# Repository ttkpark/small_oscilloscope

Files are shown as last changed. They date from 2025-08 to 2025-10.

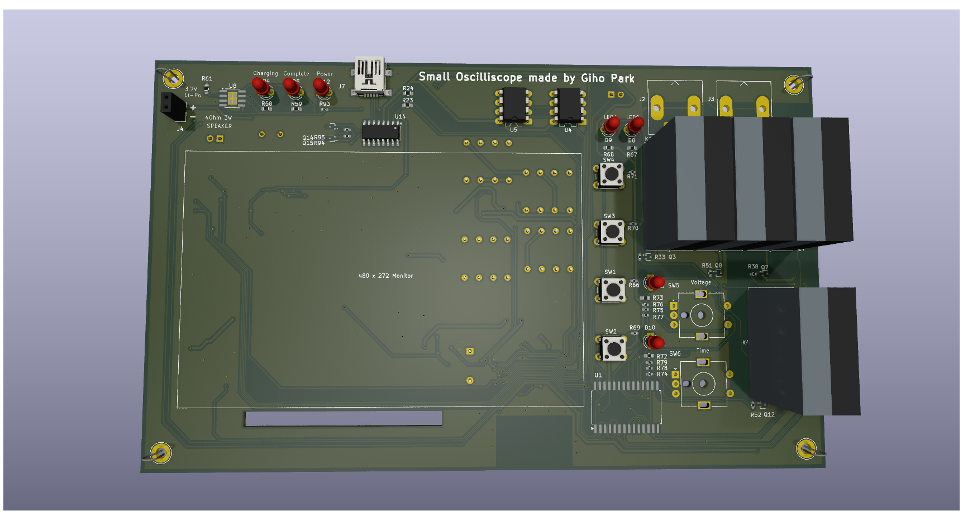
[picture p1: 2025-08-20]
hardware/small_oscilloscope/front.png

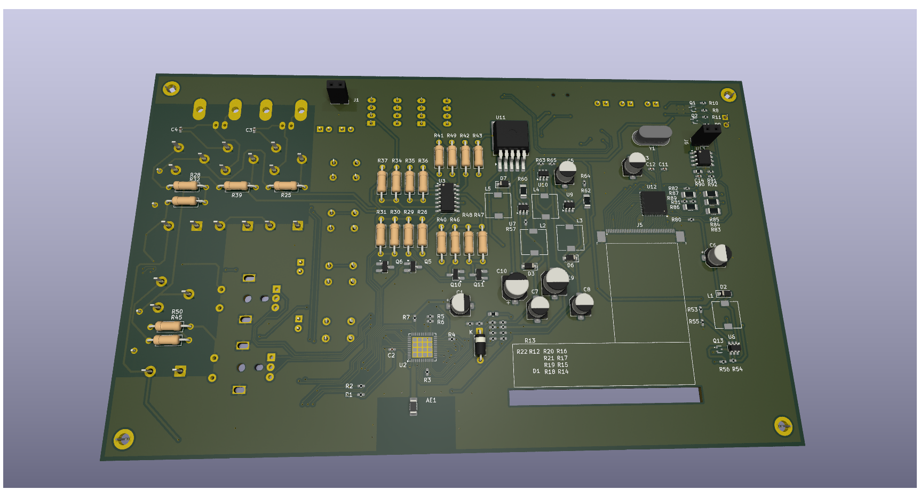
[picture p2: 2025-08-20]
hardware/small_oscilloscope/back.png

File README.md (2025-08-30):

# small_oscilloscope
480x272 small-but-full oscilloscope

## stpes to go

### 아날로그 회로
 - 오실로스코프 회로 방식 파악 필요
 - DSO138의 회로 구성을 확인

### 오실로스코프 UI
 - 제어점과 보여줄 점을 파악 필요
 - `사용자의 입력은 무엇이 되어야 하는가`
 - `오실로스코프의 아날로그 유닛에 대한 제어 범위는?`
 - `어느 점을 보여주어야 하는가`

 - 트리거 인식 : 샘플 내에서 level지점 통과 지점을 지점 정중앙으로 둔다.
 - 샘플링 후 트리거 인식이 아니라, 샘플링 하면서 트리거 인식하면 트리거 지점이 정중앙되도록 샘플 수집하고 마무리.
 - 즉 샘플링 -> 트리거 x, 트리거 -> 샘플링 o

## 전원
- 상시 전원 공급 Source : VBAT=2.7 ~ 4.2
- BAT 충전       : 5V -> VBAT=4.2 (TP4056)
- 배터리 승압 회로 : VBAT -> 5V    (EA2208)
- 양전압 생성 회로 : VBAT -> 12V   (EA2208)
- 음전압 생성 회로 : 12V -> -12V   (LM2576)
- 백라이트 회로    : VBAT -> 24V   (EA2208)
- 강하 회로       : 5V -> 3.3V    (5V->3.3V 전압 강하 보드)

## 구성요소
- 본체 중앙처리장치
   - 구성 부품 : ESP32-PICO-D4
   - 인터페이스 : GPIO, SPI, I2C, ADC, UART, DAC 제공

- GPIO 확장 칩 : CH423
   - 구성 부품 : CH423
   - 인터페이스 : 본체 인터페이스 I2C 사용
               입출력 GPIO IO0-7, 출력 GPIO OC0-15 제공

- 아날로그 어레이
   - 구성 부품 : 전압 강하 OP-AMP, 감쇠율 조절 FET 및 릴레이, AC/DC 선택 릴레이, TRIG 생성기
   - 인터페이스 : GPIO 확장 칩 OC0,OC2-6,OC8-11 사용
                본체 인터페이스 GPIO(GPIO9-10), ADC(GPIO34, GPIO4), DAC(GPIO25, GPIO26) 사용
- 그래픽
   - 구성 부품 : FT800Q-T, 480x272 Monitor
   - 인터페이스 : 본체 인터페이스 SPI, 본체 GPIO (GPIO27:INT) 사용

- 조작부
   - 구성 부품 : 버튼, ROTARY Encoder, LED
   - 인터페이스 : GPIO 확장 칩 IO0-5, OC12-15 사용

- 연결부
   - 구성 부품 : CH340, BOOT Mode selecting MOSFET
   - 인터페이스 : 본체 인터페이스 UART, 본체 GPIO 부팅 핀(GPIO0, EN) 사용

- 충전부
   - 구성 부품 : 배터리 및 TP4056
   - 인터페이스 : GPIO 확장 칩 IO6-7 사용

- 전원부
   - 구성 부품 : 레퍼런스 전압을 나누는 Voltage Divisor
   - 인터페이스 : 본체 ADC 레퍼런스 전압 포트(GPIO35-39)

# 핀맵
|position|name|usage|
|----|----|----|
|UART(TX=GPIO1,RX=GPIO3)|CH340|Interface; uploading & debugging port|
|I2C(CK=GPIO21,DA=GPIO22)|CH423s|Interface; controlls the MOSFETs|
|SPI(SCK=GPIO18,MISO=GPIO19,MOSI=GPIO23,SS=GPIO5)|FT800Q-T|Interface; graphical controller, speaker enabled, DE Mode|
|GPIO27|/INT|LCD FT800Q-T Interrupt Pin|

|GPIO12|RE1B|Digital Input; Rotary Encoder 1(Volt Div/Pos) B|
|GPIO13|RE1A|Digital Input; Rotary Encoder 1(Volt Div/Pos) A|
|GPIO14|RE0B|Digital Input; Rotray Encoder 0(Time Div/Pos) B|
|GPIO15|RE0A|Digital Input; Rotray Encoder 0(Time Div/Pos) A|

|GPIO9|TRIG0|Digital Input, interrupt; open-drain, LOW if TRIG<ADC0|
|GPIO10|TRIG1|Digital Input, interrupt; open-drain, LOW if TRIG<ADC1|
|GPIO25|TRIG|Analog Output;  Trigger Output(same level with ADC0,1 pin)|
|GPIO34|ADC0|Analog Input;  Channel 0 input|
|GPIO4|ADC1|Analog Input;  Channel 1 input|
|GPIO26|TESTPIN|1kHz Signal Output pin|

|GPIO35|VREF3V3|Analog Reference Input;  3V3(VDD) ref, Vin=V33/2|
|GPIO36|VREFBAT|Analog Reference Input;  VBAT ref, Vin=VBAT/2|
|GPIO37|VREF5V |Analog Reference Input;  5V ref, Vin=V5/4.333|
|GPIO38|VREF12V|Analog Reference Input;  12V ref,Vin=V12/6.732|
|GPIO39|VREF135|Analog Reference Input;  2.7V ref, Vin=1.35V |

|CH423s-IO0|RE0P|Input; Rotary Encoder 0 Pushbutton(LOW Active)|
|CH423s-IO1|RE1P|Input; Rotary Encoder 1 Pushbutton(LOW Active)|
|CH423s-IO2|SW0|Input; button 0(LOW ACTIVE)|
|CH423s-IO3|SW1|Input; button 1(LOW ACTIVE)|
|CH423s-IO4|SW2|Input; button 2(LOW ACTIVE)|
|CH423s-IO5|SW3|Input; button 3(LOW ACTIVE)|
|CH423s-IO6|STDBY|Input; BATTERY 충전 완료면 HIGH|
|CH423s-IO7|CHRG|Input; BATTERY 충전 중이면 HIGH|
|CH423s-OC0|Q1|Output; Line 0 DC input analog switch|
|CH423s-OC1|BACKLIGHT|Output; LCD BACKLIGHT|
|CH423s-OC2|Q3|Output; Line 0 1차 1/10 감쇠|
|CH423s-OC3|Q4|Output; Line 0 1차 1/100 감쇠|
|CH423s-OC4|Q5|Output; Line 0 2차 1/2 감쇠|
|CH423s-OC5|Q6|Output; Line 0 2차 1/5 감쇠|
|CH423s-OC6|Q7|Output; Line 1 DC input analog switch|
|CH423s-OC7|-|Output; -|
|CH423s-OC8|Q9|Output; Line 1 1차 1/10 감쇠|
|CH423s-OC9|Q10|Output; Line 1 1차 1/100 감쇠|
|CH423s-OC10|Q11|Output; Line 1 2차 1/2 감쇠|
|CH423s-OC11|Q12|Output; Line 1 2차 1/5 감쇠|
|CH423s-OC12|LED0|Output; GP LED (Red)|
|CH423s-OC13|LED1|Output; GP LED (Green)|
|CH423s-OC14|LEDRE0|Output; Rotary Encoder 0 LED (Green)|
|CH423s-OC15|LEDRE1|Output; Rotary Encoder 1 LED (Green)|

# 하드웨어 연결 및 기능 구조

## 본체 중앙처리장치
   - 구성 부품 : ESP32-PICO-D4
   - 인터페이스 : GPIO, SPI, I2C, ADC, UART, DAC 제공

## GPIO 확장 칩 : CH423
   - 구성 부품 : CH423
   - 인터페이스 : 본체 인터페이스 I2C 사용
               입출력 GPIO IO0-7, 출력 GPIO OC0-15 제공
### 인터페이스 상세
|position|name|usage|
|----|----|----|
|I2C(CK=GPIO21,DA=GPIO22)|CH423s|Interface; controlls the MOSFETs|

### 설정
- 주소는 0x20이다. (7-bit addr)
analog_test_simple.c:84 esp_err_t test_ch423_circuit_simple(uint8_t *read_data) 의 테스트 함수에서 초기화 및 읽고 쓰는 법에 대해 쓰여 있다.

## 아날로그 어레이
- 구성 부품 : 전압 강하 OP-AMP, 감쇠율 조절 FET 및 릴레이, AC/DC 선택 릴레이, TRIG 생성기
- 인터페이스 : GPIO 확장 칩 OC0,OC2-6,OC8-11 사용
             본체 인터페이스 GPIO(GPIO9-10), ADC(GPIO34, GPIO4), DAC(GPIO25, GPIO26) 사용
### 인터페이스 상세
|position|name|usage|
|----|----|----|
|GPIO9|TRIG0|Digital Input, interrupt; open-drain, LOW if TRIG<ADC0|
|GPIO10|TRIG1|Digital Input, interrupt; open-drain, LOW if TRIG<ADC1|
|GPIO25|TRIG|Analog Output;  Trigger Output(same level with ADC0,1 pin)|
|GPIO34|ADC0|Analog Input;  Channel 0 input|
|GPIO35|ADC1|Analog Input;  Channel 1 input|
|GPIO26|TESTPIN|1kHz Signal Output pin|

|CH423s-OC0|Q1|Output; Line 0 DC input analog switch|
|CH423s-OC2|Q3|Output; Line 0 1차 1/10 감쇠|
|CH423s-OC3|Q4|Output; Line 0 1차 1/100 감쇠|
|CH423s-OC4|Q5|Output; Line 0 2차 1/2 감쇠|
|CH423s-OC5|Q6|Output; Line 0 2차 1/5 감쇠|
|CH423s-OC6|Q7|Output; Line 1 DC input analog switch|
|CH423s-OC8|Q9|Output; Line 1 1차 1/10 감쇠|
|CH423s-OC9|Q10|Output; Line 1 1차 1/100 감쇠|
|CH423s-OC10|Q11|Output; Line 1 2차 1/2 감쇠|
|CH423s-OC11|Q12|Output; Line 1 2차 1/5 감쇠|

### 프로브부터 ADC 포트까지 감쇠 회로 및 전압의 관계
- [출력] - [AC/DC 선택]  -   [1차 감쇠 회로] - [2차 감쇠 회로] - 레벨 쉬프터

### 감쇠율 조정 로직 : AC/DC 선택
|Q1/Q7|상태|
|--|--|
|0|DC입력(원본)|
|1|AC입력(AC성분만)|

### 감쇠율 조정 로직 : 1차 감쇠기
|Q3/Q9|Q4/Q10|상태|
|--|--|alpha_1|
|0|0|1|
|0|1|1/100|
|1|0|1/10|
|1|1|INVALD|
- V1 = alpha_1 * Vi

### 감쇠율 조정 로직 : 2차 감쇠기
|Q5/Q11|Q6/Q12|상태|
|--|--|alpha_2|
|0|0|1|
|0|1|1/5|
|1|0|1/2|
|1|1|INVALD|
- V2 = alpha_2 * V1

### 레벨 쉬프터 식
- Vadc = 8 * V2 + (V12/7.2)

### 출력과 ADC 입력의 관계
- Vadc = 8 * alpha_2 * alpha_1 * Vi + (V12 / 7.2)
- alpha_2,alpha_1은 1차 2차 감쇠값, Vadc는 adc포트 전압, Vi는 프로브 전압, V12는 12V레인 전압

### 트리거
- TRIG0, TRIG1 핀은 pull-up되어야 한다.
|TRIG>ADCn|TRIGn|
|--|--|
|true|HIGH|
|false|LOW|

## 그래픽
   - 구성 부품 : FT800Q-T, 480x272 Monitor
   - 인터페이스 : 본체 인터페이스 SPI, 본체 GPIO (GPIO27:INT) 사용

|position|name|usage|
|----|----|----|
|SPI(SCK=GPIO18,MISO=GPIO19,MOSI=GPIO23,SS=GPIO5)|FT800Q-T|Interface; graphical controller, speaker enabled, DE Mode|
|GPIO27|/INT|LCD FT800Q-T Interrupt Pin|
|CH423s-OC1|BACKLIGHT|Output; LCD BACKLIGHT|
### 사용법
- 사전에 반드시 **CH423이 먼저 초기화되고, BACKLIGHT 핀을 LOW 해야 한다.**
- 아래 코드처럼 초기화하고, 그림을 그리고 효과음을 낸다.
```c
   // FT800 초기화
    if (!initFT800()) {
        ESP_LOGI(TAG, "FT800 test passed");
    } else {
        ESP_LOGE(TAG, "FT800 test failed");
    }
    vTaskDelay(pdMS_TO_TICKS(1000));

    spi_speedup();
    
    // FT800 사용
	 clrscr();
    while(1){
		static uint32_t frames = 0;
        uint32_t frames_old = frames;
        frames = HOST_MEM_RD32(REG_FRAMES);
        if(frames_old != frames)
        {
            lcd_start_screen(frames);
            //ESP_LOGI(TAG, "FRAMES: %ld", frames);

            char str[100];
            sprintf(str, "FRAMES: %ld", frames);
            cmd(COLOR_RGB(0xDE,0xDE,0xDE));
            cmd_text(10,230, 27,0, str);
            
            memset(str, 0, sizeof(str));
            sprintf(str, "GPIO12 = %d", gpio_get_level(12));
            cmd(COLOR_RGB(0xDE,0xDE,0xDE));
            cmd_text(470,230, 26,OPT_RIGHTX, str);

            cmd(DISPLAY());
            cmd(CMD_SWAP);	
        }
        vTaskDelay(pdMS_TO_TICKS(1));
    }

    // 소리 내기
   HOST_MEM_WR8(REG_VOL_SOUND, 0xFF);      	
   switch((frames%180)/60){
      case 0:
         HOST_MEM_WR16(REG_SOUND, 0x50);     
         break;
      case 1:
         HOST_MEM_WR16(REG_SOUND, 0x51);
         break;
      case 2:
         HOST_MEM_WR16(REG_SOUND, 0x56);
         break;
   }
   HOST_MEM_WR8(REG_PLAY, 1); 
   
```

## 조작부
   - 구성 부품 : 버튼, ROTARY Encoder, LED
   - 인터페이스 : GPIO 확장 칩 IO0-5, OC12-15 사용

|position|name|usage|
|----|----|----|
|GPIO12|RE1B|Digital Input; Rotary Encoder 1(Volt Div/Pos) B|
|GPIO13|RE1A|Digital Input; Rotary Encoder 1(Volt Div/Pos) A|
|GPIO14|RE0B|Digital Input; Rotray Encoder 0(Time Div/Pos) B|
|GPIO15|RE0A|Digital Input; Rotray Encoder 0(Time Div/Pos) A|
|CH423s-IO0|RE0P|Input; Rotary Encoder 0 Pushbutton(LOW Active)|
|CH423s-IO1|RE1P|Input; Rotary Encoder 1 Pushbutton(LOW Active)|
|CH423s-IO2|SW0|Input; button 0(LOW ACTIVE)|
|CH423s-IO3|SW1|Input; button 1(LOW ACTIVE)|
|CH423s-IO4|SW2|Input; button 2(LOW ACTIVE)|
|CH423s-IO5|SW3|Input; button 3(LOW ACTIVE)|
|CH423s-OC12|LED0|Output; GP LED (Red)|
|CH423s-OC13|LED1|Output; GP LED (Green)|
|CH423s-OC14|LEDRE0|Output; Rotary Encoder 0 LED (Green)|
|CH423s-OC15|LEDRE1|Output; Rotary Encoder 1 LED (Green)|

- 로터리 스위치의 움직임 방향, 버튼의 눌림을 알 수 있고, LED 4개로 확인할 수 있다.

## 연결부
   - 구성 부품 : CH340, BOOT Mode selecting MOSFET
   - 인터페이스 : 본체 인터페이스 UART, 본체 GPIO 부팅 핀(GPIO0, EN) 사용

|position|name|usage|
|----|----|----|
|UART(TX=GPIO1,RX=GPIO3)|CH340|Interface; uploading & debugging port|

## 충전부
   - 구성 부품 : 배터리 및 TP4056
   - 인터페이스 : GPIO 확장 칩 IO6-7 사용
|position|name|usage|
|----|----|----|
|CH423s-IO6|STDBY|Input; BATTERY 충전 완료면 HIGH|
|CH423s-IO7|CHRG|Input; BATTERY 충전 중이면 HIGH|

### 충전 상태 설명
|STDBY|CHRG|상태|
|--|--|--|
|LOW |LOW |외부전원 분리됨|
|LOW |HIGH|충전 중|
|HIGH|LOW |충전 완료|
|HIGH|HIGH|INVALID, 아마도 충전중|

## 전원부
   - 구성 부품 : 레퍼런스 전압을 나누는 Voltage Divisor
   - 인터페이스 : 본체 ADC 레퍼런스 전압 포트(GPIO35-39)

### 인터페이스 상세
|position|name|usage|
|----|----|----|
|GPIO36|VREFBAT|Analog Reference Input;  VBAT ref, Vin=VBAT/2|
|GPIO37|VREF5V |Analog Reference Input;  5V ref, Vin=V5/4.333|
|GPIO38|VREF12V|Analog Reference Input;  12V ref,Vin=V12/6.732|
|GPIO39|VREF135|Analog Reference Input;  2.7V ref, Vin=1.35V |

### 사용법
- VREF135 포트는 제너 다이오드로 연결된 거의 신뢰성 있는 전압이다. 이것을 기준으로 ADC Max Volt를 역산한다.(=VDD)
- VREFBAT의 입력을 전압으로 변환해 배터리 전압을 추출한다.
- VREF5V, 12V의 ADC입력을 전압으로 변환해 각 레인의 전압을 추출한다.
- VREF3V3은 VDD로 계산되지만, 검증용으로 예비로 전압을 추출한다.

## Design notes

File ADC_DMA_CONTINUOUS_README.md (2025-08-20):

# ESP-IDF ADC DMA Continuous Mode 구현

이 프로젝트는 ESP-IDF v5.4를 사용하여 ADC를 DMA로 끊임없이 읽는 방법을 구현한 것입니다.

## 개요

ESP32의 ADC를 Continuous Mode로 설정하여 DMA를 통해 끊임없이 데이터를 수집할 수 있습니다. 이 방식은 다음과 같은 장점이 있습니다:

- **높은 샘플링 속도**: 최대 10kHz까지 가능
- **CPU 부하 감소**: DMA가 자동으로 데이터를 처리
- **실시간 처리**: 인터럽트 기반으로 즉시 데이터 처리
- **버퍼링**: 1024 샘플 버퍼로 데이터 손실 방지

## 주요 기능

### 1. ADC Continuous Mode 초기화
```c
esp_err_t adc_dma_continuous_init(void);
```

### 2. ADC Continuous Mode 시작/정지
```c
esp_err_t adc_dma_continuous_start(void);
esp_err_t adc_dma_continuous_stop(void);
```

### 3. 데이터 접근 함수들
```c
// 전체 버퍼 데이터 가져오기
esp_err_t adc_dma_get_data(uint32_t *channel_0_data, uint32_t *channel_1_data, uint32_t *data_count);

// 최신 전압값 가져오기 (캘리브레이션 적용)
esp_err_t adc_dma_get_latest_voltage(uint32_t *voltage_ch0_mv, uint32_t *voltage_ch1_mv);

// 통계 정보 가져오기
esp_err_t adc_dma_get_statistics(uint32_t *min_ch0, uint32_t *max_ch0, uint32_t *avg_ch0,
                                uint32_t *min_ch1, uint32_t *max_ch1, uint32_t *avg_ch1);
```

## 설정

### ADC 채널
- **ADC1_CH0 (GPIO36)**: 첫 번째 채널
- **ADC1_CH1 (GPIO37)**: 두 번째 채널

### 샘플링 설정
- **샘플링 주파수**: 10kHz
- **버퍼 크기**: 1024 샘플
- **해상도**: 12비트
- **감쇠**: 11dB (0-3.3V 범위)

## 사용 방법

### 1. 기본 사용법

```c
#include "adc_dma_continuous.h"

void app_main(void) {
    // ADC DMA Continuous Mode 초기화
    esp_err_t ret = adc_dma_continuous_init();
    if (ret != ESP_OK) {
        ESP_LOGE(TAG, "ADC DMA init failed");
        return;
    }
    
    // ADC DMA Continuous Mode 시작
    ret = adc_dma_continuous_start();
    if (ret != ESP_OK) {
        ESP_LOGE(TAG, "ADC DMA start failed");
        return;
    }
    
    // 데이터 읽기
    uint32_t voltage_ch0_mv, voltage_ch1_mv;
    while (1) {
        ret = adc_dma_get_latest_voltage(&voltage_ch0_mv, &voltage_ch1_mv);
        if (ret == ESP_OK) {
            printf("CH0: %lumV, CH1: %lumV\n", voltage_ch0_mv, voltage_ch1_mv);
        }
        vTaskDelay(pdMS_TO_TICKS(100));
    }
}
```

### 2. 테스트 실행

프로젝트에 포함된 테스트를 실행하려면:

```c
// app_main.c에서 주석을 해제
start_adc_dma_test();        // 상세한 테스트
start_adc_monitor();         // 실시간 모니터링
```

### 3. 전체 버퍼 데이터 처리

```c
uint32_t channel_0_data[1024];
uint32_t channel_1_data[1024];
uint32_t data_count;

esp_err_t ret = adc_dma_get_data(channel_0_data, channel_1_data, &data_count);
if (ret == ESP_OK) {
    // 1024개의 샘플 데이터 처리
    for (int i = 0; i < data_count; i++) {
        // 데이터 처리 로직
    }
}
```

## 파일 구조

```
main/
├── adc_dma_continuous.c    # ADC DMA Continuous Mode 구현
├── adc_dma_continuous.h    # 헤더 파일
├── adc_dma_test.c         # 테스트 및 예제 코드
├── adc_dma_test.h         # 테스트 헤더 파일
└── app_main.c             # 메인 애플리케이션
```

## 빌드 및 실행

1. **프로젝트 빌드**:
   ```bash
   idf.py build
   ```

2. **플래시 및 모니터**:
   ```bash
   idf.py flash monitor
   ```

3. **ADC DMA 테스트 실행**:
   - `app_main.c`에서 `start_adc_dma_test()` 주석 해제
   - 또는 `start_adc_monitor()` 주석 해제

## 주의사항

1. **ADC 채널 제한**: ESP32에서는 ADC1과 ADC2를 동시에 사용할 때 제한이 있습니다.
2. **WiFi 사용**: ADC2를 사용할 때는 WiFi와 충돌할 수 있습니다.
3. **메모리 사용**: DMA 버퍼는 상당한 메모리를 사용합니다.
4. **캘리브레이션**: 정확한 측정을 위해서는 ADC 캘리브레이션이 필요합니다.

## 성능 특성

- **샘플링 속도**: 10kHz (설정 가능)
- **지연 시간**: < 1ms
- **CPU 사용률**: < 5% (DMA 사용으로 인해)
- **메모리 사용**: ~8KB (1024 샘플 × 2 채널 × 4바이트)

## 문제 해결

### 1. 초기화 실패
- ADC 채널이 올바르게 설정되었는지 확인
- 메모리 부족 여부 확인

### 2. 데이터 손실
- 큐 크기 증가
- 처리 속도 향상

### 3. 정확도 문제
- ADC 캘리브레이션 확인
- 노이즈 필터링 적용

## 확장 가능성

이 구현은 다음과 같이 확장할 수 있습니다:

1. **더 많은 채널**: ADC 패턴 설정 수정
2. **더 높은 샘플링 속도**: 설정 조정
3. **트리거 기능**: 특정 조건에서만 데이터 수집
4. **데이터 저장**: SD카드나 플래시에 저장
5. **실시간 분석**: FFT, 필터링 등

## 참고 자료

- [ESP-IDF ADC Continuous Mode 문서](https://docs.espressif.com/projects/esp-idf/en/latest/esp32/api-reference/peripherals/adc_continuous.html)
- [ESP32 ADC 가이드](https://docs.espressif.com/projects/esp-idf/en/latest/esp32/api-reference/peripherals/adc.html)

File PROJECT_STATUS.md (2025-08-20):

# Small Oscilloscope Project Status

## 프로젝트 개요
Small Oscilloscope는 ESP32 기반의 소형 오실로스코프 프로젝트입니다.

## 현재 상태 (2024-01-XX)

### ✅ 완료된 기능

#### 1. 하드웨어 설계
- [x] KiCad PCB 설계 완료
- [x] FT800 LCD 인터페이스 회로
- [x] CH423 I2C IO 확장 회로
- [x] 아날로그 입력 회로 (ADC)
- [x] 로터리 인코더 인터페이스
- [x] 트리거 회로
- [x] 전원 공급 회로

#### 2. 기본 소프트웨어
- [x] ESP-IDF 프로젝트 설정
- [x] FT800 LCD 드라이버 구현
- [x] 기본 GPIO 테스트
- [x] ADC 읽기 테스트
- [x] I2C CH423 테스트
- [x] 로터리 인코더 테스트

#### 3. 아날로그 테스트 시스템 ✅ **NEW**
- [x] CH423 테스트 회로 구현
- [x] 채널별 AC/DC 모드 선택 기능
- [x] 채널별 1차/2차 감쇠율 설정 (1X, 10X, 100X, 1000X)
- [x] 실시간 시리얼 출력 기능
- [x] 웹 서버를 통한 파형 표시
- [x] Python 테스트 스크립트
- [x] 종합 테스트 시스템

### 🔄 진행 중인 작업

#### 1. LCD 모니터 문제 해결
- [ ] FT800 LCD 동작 문제 디버깅
- [ ] SPI 통신 최적화
- [ ] 백라이트 제어 개선

#### 2. 아날로그 회로 테스트
- [ ] 실제 하드웨어에서 아날로그 테스트 실행
- [ ] ADC 캘리브레이션 개선
- [ ] 노이즈 필터링 적용

### 📋 예정된 작업

#### 1. 오실로스코프 핵심 기능
- [ ] 트리거 시스템 구현
- [ ] 시간축 제어 (Time/Div)
- [ ] 전압축 제어 (Volt/Div)
- [ ] 파형 저장 및 재생
- [ ] 측정 기능 (주파수, 진폭, 주기 등)

#### 2. 사용자 인터페이스
- [ ] LCD 터치 인터페이스 구현
- [ ] 메뉴 시스템
- [ ] 설정 저장/불러오기
- [ ] 다국어 지원

#### 3. 고급 기능
- [ ] FFT 스펙트럼 분석
- [ ] 자동 측정 기능
- [ ] 데이터 로깅
- [ ] 원격 제어 인터페이스

## 기술 스택

### 하드웨어
- **MCU**: ESP32-WROOM-32
- **LCD**: FT800 (SPI 인터페이스)
- **IO 확장**: CH423 (I2C)
- **ADC**: ESP32 내장 ADC (12-bit)
- **인코더**: ALPS EC11E

### 소프트웨어
- **프레임워크**: ESP-IDF v5.4
- **언어**: C/C++
- **통신**: SPI, I2C, UART
- **웹 서버**: ESP HTTP Server
- **테스트 도구**: Python + matplotlib

## 파일 구조

```
small_oscilloscope/
├── main/
│   ├── app_main.c              # 메인 애플리케이션
│   ├── ft800.c                 # FT800 LCD 드라이버
│   ├── ft800.h                 # FT800 헤더
│   ├── oscilloscope_test.c     # 기본 테스트 함수
│   ├── oscilloscope_test.h     # 기본 테스트 헤더
│   ├── analog_test.c           # 아날로그 테스트 시스템 ✅
│   ├── analog_test.h           # 아날로그 테스트 헤더 ✅
│   └── CMakeLists.txt          # 빌드 설정
├── hardware/
│   └── small_oscilloscope/     # KiCad 프로젝트
├── test_analog.py              # Python 테스트 스크립트 ✅
├── ANALOG_TEST_README.md       # 아날로그 테스트 문서 ✅
├── PROJECT_STATUS.md           # 이 파일
└── README.md                   # 프로젝트 개요
```

## 최근 업데이트 (2024-01-XX)

### 아날로그 테스트 시스템 구현 완료 ✅

요청하신 모든 아날로그 테스트 기능을 구현했습니다:

1. **CH423 테스트 회로**
   - I2C를 통한 CH423 IO 확장 칩 테스트
   - 테스트 패턴 출력 및 읽기 기능
   - 자동 감지 및 오류 처리

2. **채널별 AC/DC 모드 선택**
   - 각 채널 독립적으로 DC/AC 모드 설정
   - 실시간 모드 변경 지원
   - 설정 상태 시리얼 출력

3. **감쇠율 설정**
   - 1차/2차 감쇠율 독립 설정 (1X, 10X, 100X, 1000X)
   - 채널별 개별 설정 지원
   - 설정값 실시간 모니터링

4. **시리얼 출력**
   - 10Hz 실시간 데이터 출력
   - ADC 값, 채널 설정, CH423 상태 포함
   - 구조화된 데이터 형식

5. **웹 인터페이스**
   - 실시간 파형 표시 (Canvas 기반)
   - 채널 설정 웹 인터페이스
   - 실시간 데이터 모니터링
   - 반응형 디자인

6. **Python 테스트 도구**
   - 시리얼 데이터 수집 및 파싱
   - matplotlib을 통한 파형 플롯
   - 명령행 인터페이스
   - 자동화된 테스트 기능

### 주요 특징

- **실시간 성능**: 10Hz 업데이트율로 실시간 모니터링
- **멀티태스킹**: FreeRTOS 기반 병렬 처리
- **웹 기반**: 브라우저를 통한 원격 제어
- **확장 가능**: 모듈화된 설계로 기능 확장 용이
- **문서화**: 상세한 API 문서 및 사용법 제공

## 다음 단계

1. **하드웨어 테스트**: 실제 보드에서 아날로그 테스트 실행
2. **LCD 문제 해결**: FT800 동작 문제 디버깅
3. **성능 최적화**: ADC 샘플링율 및 정확도 개선
4. **오실로스코프 기능**: 트리거, 시간축, 측정 기능 구현

## 빌드 및 테스트

```bash
# 프로젝트 빌드
idf.py build

# ESP32 플래시 및 모니터링
idf.py flash monitor

# Python 테스트 스크립트 실행
python test_analog.py --port COM3 --plot
```

## 참고 자료

- [ESP-IDF Programming Guide](https://docs.espressif.com/projects/esp-idf/en/latest/esp32/)
- [FT800 Programming Guide](https://www.ftdichip.com/Support/Documents/ProgramGuides/FT800_Programmers_Guide.pdf)
- [CH423 Datasheet](https://www.wch.cn/downloads/CH423DS1_PDF.html)
- [ESP HTTP Server](https://docs.espressif.com/projects/esp-idf/en/latest/esp32/api-reference/protocols/esp_http_server.html)

---

**마지막 업데이트**: 2024-01-XX
**상태**: 아날로그 테스트 시스템 구현 완료 ✅

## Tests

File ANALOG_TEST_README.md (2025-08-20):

# Small Oscilloscope - 아날로그 테스트 기능

이 문서는 Small Oscilloscope 프로젝트의 아날로그 회로 테스트 기능에 대한 설명입니다.

## 기능 개요

아날로그 테스트 시스템은 다음 기능들을 제공합니다:

1. **CH423 테스트 회로**: I2C를 통한 CH423 IO 확장 칩 테스트
2. **아날로그 신호 출력**: 채널별 AC/DC 모드 선택
3. **감쇠율 설정**: 채널별 1차/2차 감쇠율 설정 (1X, 10X, 100X, 1000X)
4. **실시간 시리얼 출력**: ADC 읽기 값과 설정 정보를 시리얼로 출력
5. **웹 인터페이스**: 브라우저를 통한 실시간 파형 표시 및 제어

## 하드웨어 요구사항

- ESP32 개발 보드
- CH423 IO 확장 칩 (I2C 주소: 0x40)
- ADC 입력 채널 2개 (GPIO36, GPIO37)
- I2C 연결 (SDA: GPIO21, SCL: GPIO22)

## 빌드 및 플래시

```bash
# 프로젝트 빌드
idf.py build

# ESP32에 플래시
idf.py flash monitor
```

## 사용법

### 1. 기본 실행

ESP32를 플래시하고 실행하면 자동으로 다음이 시작됩니다:

- 아날로그 테스트 시스템 초기화
- 웹 서버 시작 (기본 포트: 80)
- 시리얼 출력 태스크 시작 (10Hz)
- CH423 테스트 실행

### 2. 시리얼 모니터링

시리얼 포트를 통해 실시간 데이터를 확인할 수 있습니다:

```
ADC: CH0=1234mV, CH1=5678mV | CH0: DC, 1X/10X, 1500mV | CH1: AC, 10X/100X, 2000mV
```

### 3. 웹 인터페이스

브라우저에서 `http://[ESP32_IP]`로 접속하여 다음 기능을 사용할 수 있습니다:

- **연결 상태 확인**: 실시간 연결 상태 표시
- **채널 설정**: 각 채널의 AC/DC 모드, 감쇠율, 출력 전압 설정
- **파형 표시**: 실시간 ADC 값 그래프 표시
- **데이터 모니터링**: 현재 ADC 값과 설정 정보 표시

### 4. Python 테스트 스크립트

`test_analog.py` 스크립트를 사용하여 고급 테스트 기능을 사용할 수 있습니다:

```bash
# 기본 모니터링 (60초)
python test_analog.py --port COM3

# 데이터 플롯과 함께 모니터링
python test_analog.py --port COM3 --plot --duration 120

# CH423 테스트
python test_analog.py --port COM3 --test-ch423

# 채널 설정
python test_analog.py --port COM3 --set-ch0 DC 1 10 1500
python test_analog.py --port COM3 --set-ch1 AC 10 100 2000
```

## API 함수

### 초기화 및 설정

```c
// 아날로그 테스트 시스템 초기화
esp_err_t analog_test_init(void);

// 채널 설정
esp_err_t set_channel_config(uint8_t channel, const channel_config_t *config);

// 아날로그 출력 설정
esp_err_t set_analog_output(uint8_t channel, uint16_t voltage_mv);

// AC/DC 모드 설정
esp_err_t set_ac_dc_mode(uint8_t channel, ac_dc_mode_t mode);

// 감쇠율 설정
esp_err_t set_attenuation(uint8_t channel, attenuation_t primary, attenuation_t secondary);
```

### 테스트 함수

```c
// CH423 테스트
esp_err_t test_ch423_circuit(uint8_t *read_data);

// 종합 테스트 실행
esp_err_t run_analog_comprehensive_test(analog_test_results_t *results);

// 테스트 결과 출력
void print_analog_test_results(const analog_test_results_t *results);
```

### 서비스 함수

```c
// 시리얼 출력 태스크 시작
esp_err_t start_serial_output_task(void);

// 웹 서버 시작
esp_err_t start_web_server(void);
```

## 데이터 구조체

### 채널 설정

```c
typedef struct {
    ac_dc_mode_t ac_dc_mode;        // AC/DC 모드
    attenuation_t primary_atten;    // 1차 감쇠율
    attenuation_t secondary_atten;  // 2차 감쇠율
    uint16_t output_voltage_mv;     // 출력 전압 (mV)
    bool enabled;                   // 활성화 여부
} channel_config_t;
```

### 테스트 결과

```c
typedef struct {
    bool ch423_test_passed;         // CH423 테스트 통과 여부
    bool analog_output_test_passed; // 아날로그 출력 테스트 통과 여부
    bool serial_output_test_passed; // 시리얼 출력 테스트 통과 여부
    uint8_t ch423_read_data;        // CH423 읽기 데이터
    uint32_t adc_readings[2];       // ADC 읽기 값 (mV)
    channel_config_t channel_configs[2]; // 채널 설정
} analog_test_results_t;
```

## 설정 옵션

### AC/DC 모드
- `MODE_DC`: DC 모드 (직류)
- `MODE_AC`: AC 모드 (교류)

### 감쇠율
- `ATTEN_1X`: 1배 (감쇠 없음)
- `ATTEN_10X`: 10배 감쇠
- `ATTEN_100X`: 100배 감쇠
- `ATTEN_1000X`: 1000배 감쇠

## 웹 인터페이스 사용법

1. **연결**: ESP32의 IP 주소로 브라우저 접속
2. **채널 설정**: 각 채널의 설정을 변경하고 "Apply" 버튼 클릭
3. **파형 확인**: 실시간 파형이 캔버스에 표시됨
4. **데이터 모니터링**: 현재 ADC 값과 설정 정보 확인

## 문제 해결

### CH423 테스트 실패
- I2C 연결 확인 (SDA: GPIO21, SCL: GPIO22)
- 전원 공급 확인
- I2C 주소 확인 (0x40)

### 웹 서버 접속 불가
- ESP32 IP 주소 확인
- 네트워크 연결 상태 확인
- 방화벽 설정 확인

### ADC 읽기 오류
- ADC 핀 연결 확인 (GPIO36, GPIO37)
- 입력 전압 범위 확인 (0-3.3V)
- ADC 캘리브레이션 확인

## 로그 메시지

주요 로그 태그:
- `ANALOG_TEST`: 아날로그 테스트 관련 로그
- `SMALL_OSCILLOSCOPE`: 메인 애플리케이션 로그

로그 레벨 설정:
```bash
# 로그 레벨 설정
idf.py menuconfig
# Component config -> Log output -> Default log verbosity
```

## 성능 특성

- **ADC 샘플링**: 10Hz (100ms 간격)
- **웹 업데이트**: 실시간 (10Hz)
- **시리얼 출력**: 10Hz
- **메모리 사용량**: 약 8KB (태스크 스택)

## 향후 개선 사항

1. **WebSocket 지원**: 실시간 양방향 통신
2. **데이터 저장**: SD 카드 또는 플래시 메모리에 데이터 저장
3. **고급 필터링**: 디지털 필터 적용
4. **트리거 기능**: 자동 트리거 및 동기화
5. **캘리브레이션**: 자동 ADC 캘리브레이션

## 라이선스

이 프로젝트는 MIT 라이선스 하에 배포됩니다.

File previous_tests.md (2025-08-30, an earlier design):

# small_oscilloscope
480x272 small-but-full oscilloscope

# 오실로스코프 만들기

## 개발 환경 설정

### ESP-IDF 설치 (Windows)

1. **ESP-IDF 다운로드 및 설치**
   ```bash
   # Git 설치 후
   git clone --recursive https://github.com/espressif/esp-idf.git
   cd esp-idf
   install.bat
   ```

2. **환경 변수 설정**
   ```bash
   # ESP-IDF 환경 활성화
   export.bat
   ```

3. **프로젝트 빌드**
   ```bash
   cd small_oscilloscope
   idf.py build
   idf.py -p COM_PORT flash
   idf.py -p COM_PORT monitor
   ```

### 대안: ESP-IDF Windows Installer 사용
- [ESP-IDF Windows Installer](https://dl.espressif.com/dl/esp-idf/) 다운로드
- 설치 후 자동으로 환경이 설정됨
## 목표
- 아날로그 2채널 입력 가능한 오실로스코프
- 디지털 입력 모드 구현 및 신호 분석이 되는 오실로스코프
- 노브 컨트롤, 로터리 인코더 컨트롤
- DSO138 오실로스코프보다 더 좋은, Proteus의 오실로스코프 같은 오실로스코프
- Battery-Powered, 충전 가능
- 속도는 ESP32 구성의 최대치 (기존 칩 쓰거나, 문제가 크면 ESP32-C6 사용)

## stpes to go

### 아날로그 회로
 - 오실로스코프 회로 방식 파악 필요
 - DSO138의 회로 구성을 확인

### 오실로스코프 UI
 - 제어점과 보여줄 점을 파악 필요
 - `사용자의 입력은 무엇이 되어야 하는가`
 - `오실로스코프의 아날로그 유닛에 대한 제어 범위는?`
 - `어느 점을 보여주어야 하는가`

 - 트리거 인식 : 샘플 내에서 level지점 통과 지점을 지점 정중앙으로 둔다.
 - 샘플링 후 트리거 인식이 아니라, 샘플링 하면서 트리거 인식하면 트리거 지점이 정중앙되도록 샘플 수집하고 마무리.
 - 즉 샘플링 -> 트리거 x, 트리거 -> 샘플링 o

- Chipset : LOLIN D32
- Display : FT800Q-R

- Analog : 
- [ ] +5V 벅부스트 제너레이터(LOLIN 내장, but 배터리 회로 제작 예정)
- [x] -5V 생성기(NE555 + 쇼트키)
- [ ] +3.3 생성기
- [ ] OPAMP
- [ ] BNC
- [x] 로터리 스위치
- [ ] +12V 생성기(음전압을 위한 생성기)

LCD : 480x272 Monitor
# pin mapping
|position|name|usage|
|----|----|----|
|UART(TX=GPIO1,RX=GPIO3)|CH340|Interface; uploading & debugging port|
|I2C(CK=GPIO21,DA=GPIO22)|CH423s|Interface; controlls the MOSFETs|
|SPI(SCK=GPIO18,MISO=GPIO19,MOSI=GPIO23,SS=GPIO5)|FT800Q-T|Interface; graphical controller, speaker enabled, DE Mode|
|GPIO27|/INT|LCD FT800Q-T Interrupt Pin|

|GPIO12|RE1B|Digital Input; Rotary Encoder 1(Volt Div/Pos) B|
|GPIO13|RE1A|Digital Input; Rotary Encoder 1(Volt Div/Pos) A|
|GPIO14|RE0B|Digital Input; Rotray Encoder 0(Time Div/Pos) B|
|GPIO15|RE0A|Digital Input; Rotray Encoder 0(Time Div/Pos) A|

|GPIO9|TRIG0|Digital Input, interrupt; open-drain, LOW if TRIG<ADC0|
|GPIO10|TRIG1|Digital Input, interrupt; open-drain, LOW if TRIG<ADC1|
|GPIO25|TRIG|Analog Output;  Trigger Output(same level with ADC0,1 pin)|
|GPIO34|ADC0|Analog Input;  Channel 0 input|
|GPIO4|ADC1|Analog Input;  Channel 1 input|
|GPIO26|TESTPIN|1kHz Signal Output pin|

|GPIO36|SENSOR_VP  |Analog Reference Input;  VBAT ref, Vin=VBAT/2|
|GPIO37|SENSOR_CAPP|Analog Reference Input;  5V ref, Vin=V5/4.333|
|GPIO38|SENSOR_CAPN|Analog Reference Input;  12V ref,Vin=V12/6.732|
|GPIO39|SENSOR_VN  |Analog Reference Input;  2.7V ref, Vin=1.35V |

|CH423s-IO0|RE0P|Input; Rotary Encoder 0 Pushbutton(LOW Active)|
|CH423s-IO1|RE1P|Input; Rotary Encoder 1 Pushbutton(LOW Active)|
|CH423s-IO2|SW0|Input; button 0(LOW ACTIVE)|
|CH423s-IO3|SW1|Input; button 1(LOW ACTIVE)|
|CH423s-IO4|SW2|Input; button 2(LOW ACTIVE)|
|CH423s-IO5|SW3|Input; button 3(LOW ACTIVE)|
|CH423s-IO6|STDBY|Input; BATTERY 충전 완료면 HIGH|
|CH423s-IO7|CHRG|Input; BATTERY 충전 중이면 HIGH|
|CH423s-OC0|Q1|Output; Line 0 DC input analog switch|
|CH423s-OC1|BACKLIGHT|Output; LCD BACKLIGHT|
|CH423s-OC2|Q3|Output; Line 0 1차 1/10 감쇠|
|CH423s-OC3|Q4|Output; Line 0 1차 1/100 감쇠|
|CH423s-OC4|Q5|Output; Line 0 2차 1/2 감쇠|
|CH423s-OC5|Q6|Output; Line 0 2차 1/5 감쇠|
|CH423s-OC6|Q7|Output; Line 1 DC input analog switch|
|CH423s-OC7|-|Output; -|
|CH423s-OC8|Q9|Output; Line 1 1차 1/10 감쇠|
|CH423s-OC9|Q10|Output; Line 1 1차 1/100 감쇠|
|CH423s-OC10|Q11|Output; Line 1 2차 1/2 감쇠|
|CH423s-OC11|Q12|Output; Line 1 2차 1/5 감쇠|
|CH423s-OC12|LED0|Output; GP LED (Red)|
|CH423s-OC13|LED1|Output; GP LED (Green)|
|CH423s-OC14|LEDRE0|Output; Rotary Encoder 0 LED (Green)|
|CH423s-OC15|LEDRE1|Output; Rotary Encoder 1 LED (Green)|

# 아날로그 구조

[출력] - [AC/DC 선택]  -   [1차 감쇠 회로] - [2차 감쇠 회로] - 레벨 쉬프터

## AC/DC 선택
|Q1/Q7|Q2/Q8|상태|
|--|--|--|
|0|0|FLOATING|
|0|1|INVALD(DC입력)|
|1|0|DC입력(원본)|
|1|1|INVALD(DC입력)|

## 1차 감쇠기
|Q3/Q9|Q4/Q10|상태|
|--|--|--|
|0|0|감쇠 없음|
|0|1|1/100 감쇠|
|1|0|1/10 감쇠|
|1|1|INVALD|
V1 = alpha_1 * Vi

## 2차 감쇠기
|Q5/Q11|Q6/Q12|상태|
|--|--|--|
|0|0|감쇠 없음|
|0|1|1/5 감쇠|
|1|0|1/2 감쇠|
|1|1|INVALD|
V2 = alpha_2 * V1

## 레벨 쉬프터 식
Vadc = 8 * V2 + (3.3/2)

# 핀 전압 오류
| pin | Z_VCC | Z_GND |
|-----|---|---|
| SS | inf | inf |
| SCK | 1.5k | 43 |
| MISO | 1.5k | 74 |
| MOSI | 1.5k | 100 |

# 결론
- VCore를 그냥 3.3V에 연결해서 칩이 뜨거워졌고, 코어가 파괴된걸로 추정.
- MOSI 문제는 Logic Pirate의 문제였다
- 코어 회로 수정

### 음전압 충분하지 못한 문제
- 3.3V -> -1.7V
- 5V로 개조 -> -3.N V
- 12V 외부 변환기 입력 -> -9V, 성공적인 레귤레이션
- 해결책 : 충분한 12V대 제너레이터를 만들거나 음전압 SMPS를 만들기

### 모니터 전원부 24V 문제
- 1. 저항 잊어먹음. 무부하 24V가 연결됨
- 2. 바로 옆의 GND와 충돌.

계획
- 이번 주 내로 부품 주문, 기판 주문(Stensil)
- ESP32 모듈도 내장으로 같이 붙이기 (PICO-D4 / WROOM32) C6은 싸지만 너무 느릴듯

- 배터리 관리 회로 따로 만들기
   - 충전 회로
   - 승압 회로

# 최종 확정 사항
## 전원
- 상시 전원 공급 Source : VBAT=2.7 ~ 4.2
- BAT 충전       : 5V -> VBAT=4.2 (TP4056)
- 배터리 승압 회로 : VBAT -> 5V    (EA2208)
- 양전압 생성 회로 : VBAT -> 12V   (EA2208)
- 음전압 생성 회로 : 12V -> -12V   (LM2576)
- 백라이트 회로    : VBAT -> 24V   (EA2208)
- 강하 회로       : 5V -> 3.3V    (EA8105)

## 칩
- 아날로그 회로 테스트, 결과에 따른 아날로그 회로 확정
   - [x] 아날로그 회로 작동여부 테스트 (1시간)
   - [x] 노이즈 정도에 따라 아날로그 전원 필요 여부 판단 (30분)
- LCD, Graphic과 같이 Stensil로 기판 박제 예정
- Stensil로 하는것과 차이가 있는지 확인 필요
   - [x] 회로 만들기(3~5시간 -> 6+6시간+2시간)
      - Processor : ESP32-PICO
         - JLCPCB Stensil
      - 충전 : TP4056 + USB 입력 회로(CH340C 연결) <CH340 추가 구매 필요 okay> 
	     - USB는 기용이가 쓰는 걸로 (DPDM, VBUS 다 있는 USB-C)
      - Relay : JQ1-5V-F (5V) 
         - Relay1[NC=DC,NO=AC], Relay2[NC=/1,NO=/10]
         - 2라인 총 4개 필요
         - 나머지 1차/100, 2차/2, 2차/5는 MOSFET로. <MOSFET 추가 구매 필요 okay> 
      - LM2576 12V
      - EA2208 24V, 12V  <Inductor 추가 구매 필요 (40mOhm, ~10uH, 1.2MHz Small Loss) 24V 라인에 비해 12V 라인은 더 용량이 커야함> 
      - EA2208 배선 전 꼭 확인하기
         <1 High current path traces need to be widened.>
         <2 Place the input and output capacitors as close as possible to the device to reduce noiseinterference.>
         <3 The GND pin should be connected to a large area ground plane>
         <4 Keep the feedback path (from VOUT to FBK) away from the noise node (ex. SWITCH). >

      - 전원 회로, LCD회로, 아날로그 회로, USB 회로 작성 완료. 메인 프로세서 부분만 남음.

      - 안테나 선 두께는 60mil로 해야함. JLCPCB Impeadence 계산기로 계산하자.
      - 정합은 하지 않는 걸로.
   - [ ] <엘레파츠 필요부품 정리 및 장바구니(1시간, 배송 9일 소요)>
      -  <button/headersocket 추가 구매 필요 okay> 
   - [ ] PCB Assembly 출력파일 조절 및 부품 포맷 통일 및 배치 파일 생성(1시간)
   - [ ] JLCPCB 사이트에서 견적 비교하기 (배송 4일 소요)

   - [x] 엘레파츠 주문 및 JLCPCB 주문
   - 6/27 : 엘레파츠 35,519
   - 6/27 : JLCPCB 3,577
   - 7/18 : 엘레파츠 44,515
   - 7/19 : JLCPCB 43,199  총 소비 : 126,810

   - 8/19 : 1차 Stencil 회로 완성, ESP32-PICO-D4 인식 성공, BACKLIGHT 성공

## 아날로그 테스트 결과(7/15)
- CH423 Test : 성공
   - ESP-IDF의 모든 함수의 어드레스는 W/R을 제외한, 내부적으로 1칸 좌쉬프트 처리하는 어드레스이다.
   - 8-bit 기준 0x48 주소를 0x24 주소로 했더니 잘 인식했다.
   - i2c 스캐너를 활용해 칩이 인식된 것을 확인했다.
   - 0x22, 0x23 주소를 통해 OC0~16을 제어하고, 0x20에 0x49를 명령하고 바이트를 읽으면 IO0~7까지 데이터를 읽을 수 있다.(사전에 IO처리 필요)
   - analog_test_simple 85:182에 있음
- 아날로그 회로 테스트
   - -5V 라인이 불안정하다.(-4.75V)
   - 기본적으로 1차에서 1/10 감쇠되길래 확인해보니, MOSFET가 무슨 일인지 Rds(off)가 2kOhm쯤 되었다. 옆 라인의 MOSFET는 Rds(off)=146k정도가 되었고, 이는 중대한 문제다.
   - Analog Switch가 전혀 동작하지 않았다. Relay로 해야할 것 같다.
   - 1/10 감쇠 1채널만 스위칭 오류
   - AC/DC부분, 1차 증폭 부분만 릴레이를 사용하기
   - 1/10, 1/100, 1/2, 1/5 1차 2차 감쇠 모두 적용 성공
   - ADC에 CAP를 설치하거나 ADC 칩을 달아야 할 것 같다(ESP32 내부 ADC 작동 잘 못함)
   - i2c ADC 또는 SPI ADC 설치 필요
- 아날로그 전원은 넣지 않기로 했다. 다만 vcc 라인을 좀 더 신경써서 작업해야한다. 디지털과 잡음이 생기지 않도록 갈라서 배선하고, 전원 소스를 잘 놓아야 한다.

- 노브에 1k 저항 직렬 연결 및 캐패시터 병렬 연결
- GPIO4 -> GPIO35 : ADC2는 와이파이 사용  중엔 사용불가.
- 3.3V 전원 이상함.
- 릴레이 핀맵 다름.
- CH340C 전원을 USB 말고 5V로 변경.
- 릴레이에 5V 전원 사이에 10옴 저항 연결
- R82 그래픽드라이버 칩단에 캐패시터 연결
- SPI 그래픽칩과 본체 사이 저항 10옴 삭제
-

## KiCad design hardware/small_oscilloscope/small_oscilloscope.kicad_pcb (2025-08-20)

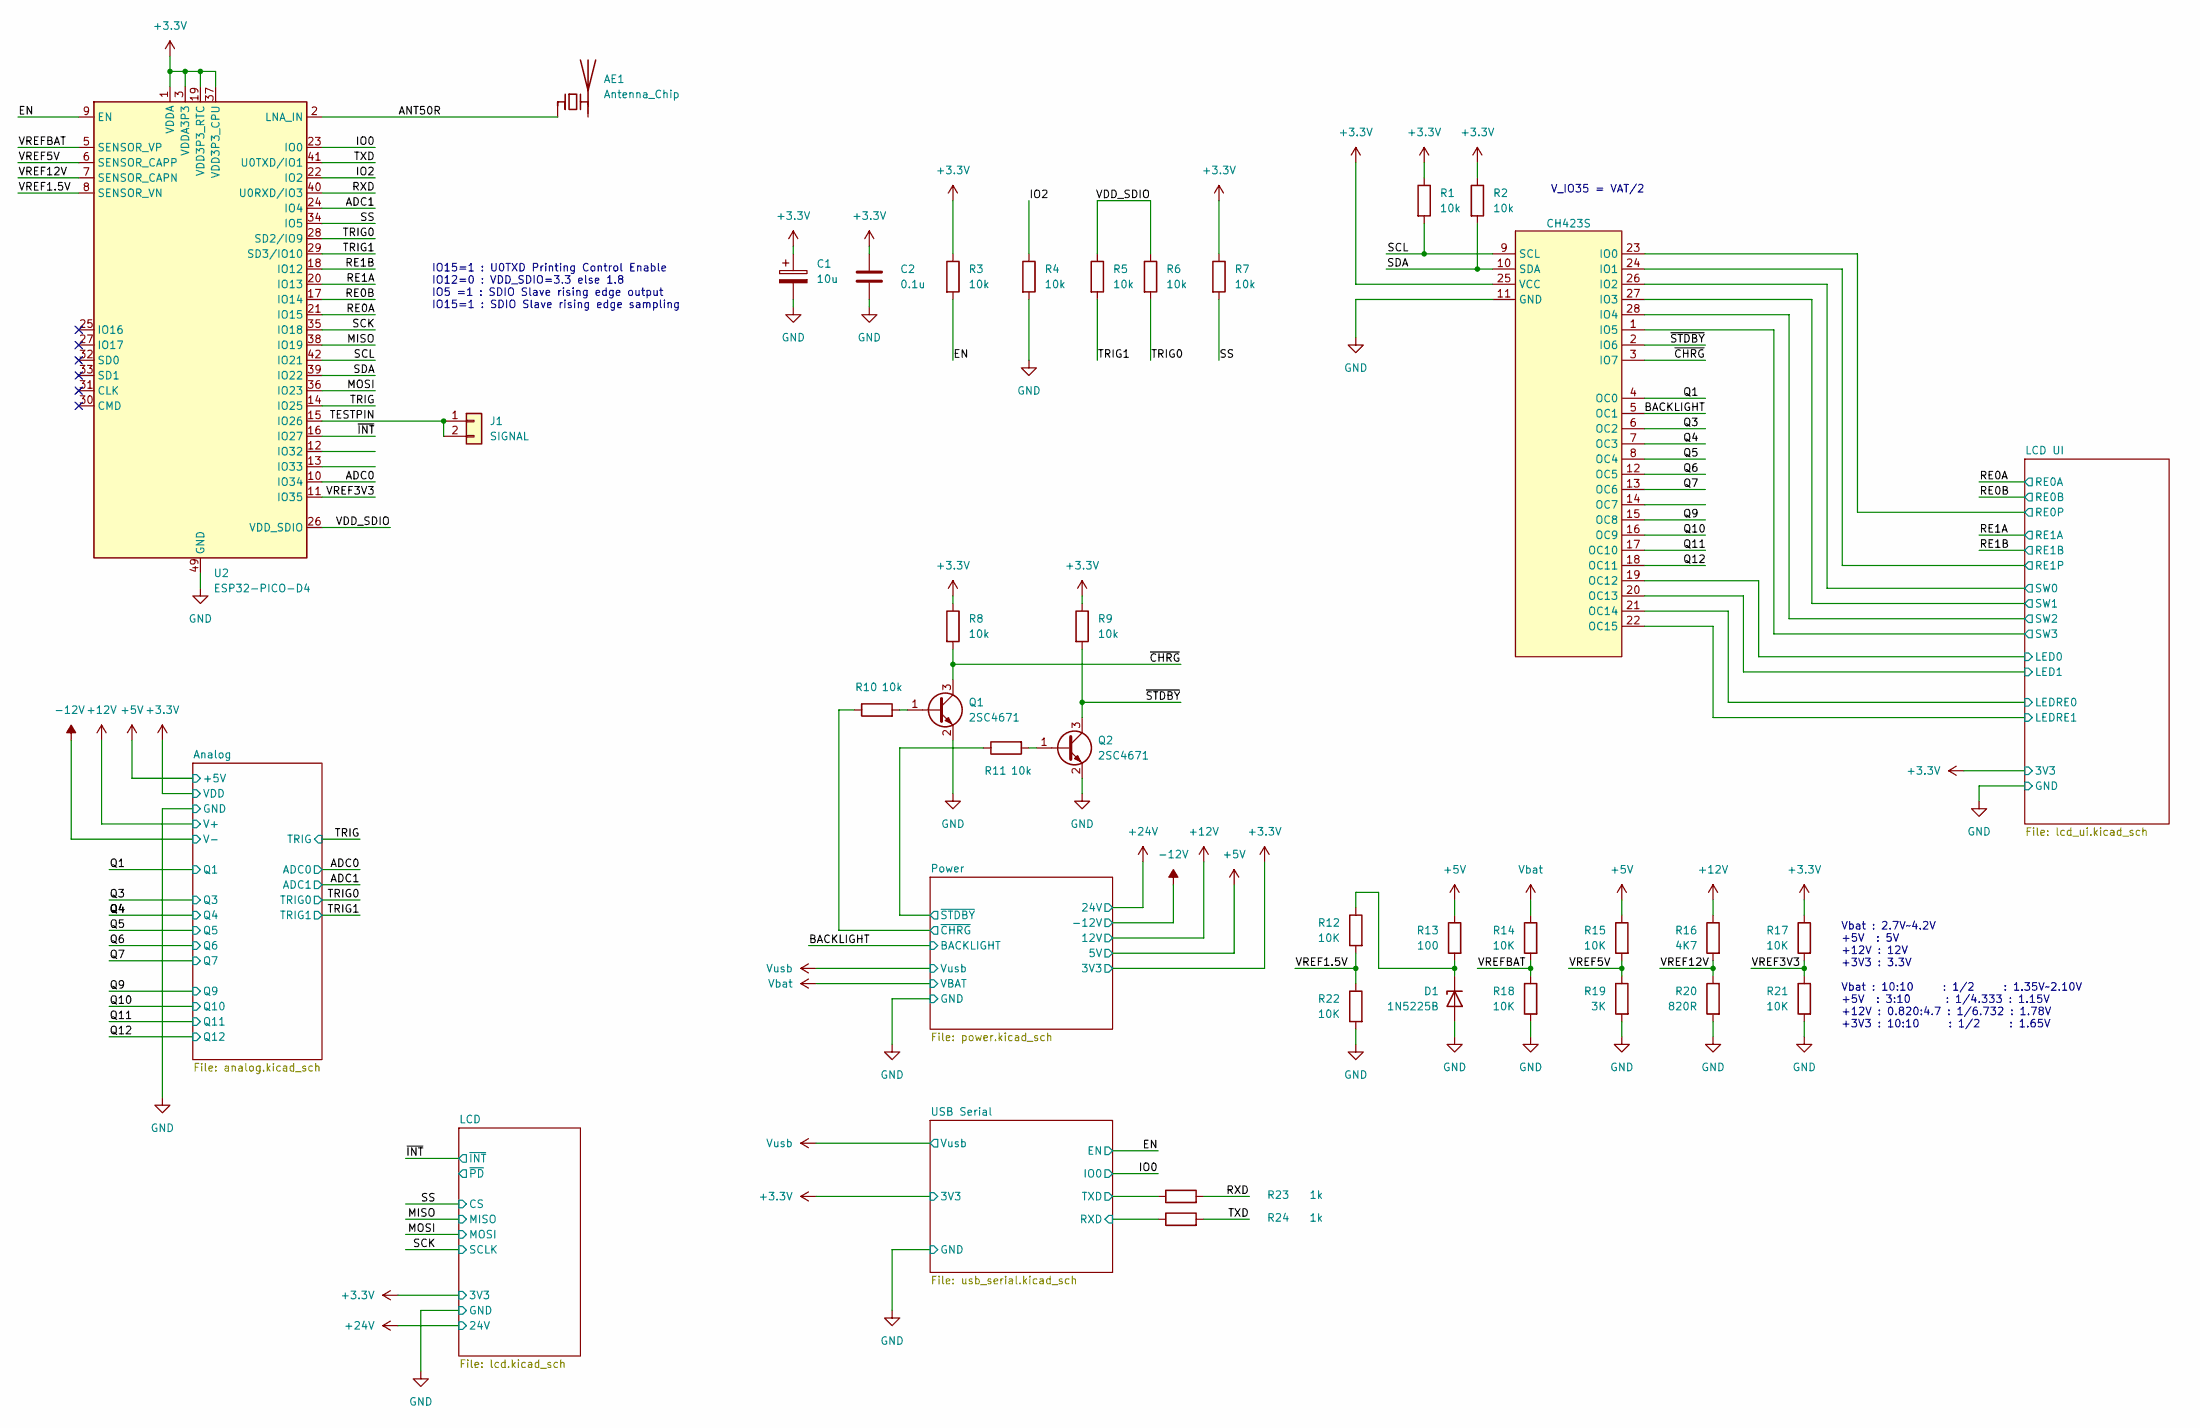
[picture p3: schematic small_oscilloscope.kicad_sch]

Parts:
AE1: Antenna_Chip; L_1206_3216Metric_Pad1.22x1.90mm_HandSolder
C1: 10u; CP_Elec_5x5.3
C2: 0.1u; C_0402_1005Metric_Pad0.74x0.62mm_HandSolder
D1: 1N5225B; D_A-405_P7.62mm_Horizontal
J1: SIGNAL; PinSocket_1x02_P2.54mm_Vertical
Q1, Q2: 2SC4671; SOT-523
R1, R2, R3, R4, R5, R6, R7, R8, R9, R10, R11: 10k; R_0402_1005Metric_Pad0.72x0.64mm_HandSolder
R12, R14, R15, R17, R18, R21, R22: 10K; R_0402_1005Metric_Pad0.72x0.64mm_HandSolder
R13: 100; R_0603_1608Metric_Pad0.98x0.95mm_HandSolder
R16: 4K7; R_0402_1005Metric_Pad0.72x0.64mm_HandSolder
R19: 3K; R_0402_1005Metric_Pad0.72x0.64mm_HandSolder
R20: 820R; R_0402_1005Metric_Pad0.72x0.64mm_HandSolder
R23, R24: 1k; R_0603_1608Metric_Pad0.98x0.95mm_HandSolder
U1: CH423S; SOP-28_8.4x18.16mm_P1.27mm
U2: ESP32-PICO-D4; QFN-48-1EP_7x7mm_P0.5mm_EP5.3x5.3mm

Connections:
+3.3V: C1.1, C2.1, R1.1, R2.1, R3.1, R7.1, R8.1, R9.1, R17.1, U1.25 (VCC), U2.1 (VDDA), U2.3 (VDDA3P3), U2.4 (VDDA3P3), U2.19 (VDD3P3_RTC), U2.37 (VDD3P3_CPU), U2.43 (VDDA), U2.46 (VDDA); also elsewhere on the board
+5V: R13.1, R15.1; also elsewhere on the board
+12V: R16.1; also elsewhere on the board
/ADC0: U2.10 (IO34); also elsewhere on the board
/ADC1: U2.24 (IO4); also elsewhere on the board
/ANT50R: AE1.1 (FEED), U2.2 (LNA_IN)
/BACKLIGHT: U1.5 (OC1); also elsewhere on the board
/EN: R3.2, U2.9 (EN); also elsewhere on the board
/IO0: U2.23 (IO0); also elsewhere on the board
/IO2: R4.1, U2.22 (IO2)
/LCD UI/LED0: U1.19 (OC12); also elsewhere on the board
/LCD UI/LED1: U1.20 (OC13); also elsewhere on the board
/LCD UI/LEDRE0: U1.21 (OC14); also elsewhere on the board
/LCD UI/LEDRE1: U1.22 (OC15); also elsewhere on the board
/LCD UI/RE0P: U1.23 (IO0); also elsewhere on the board
/LCD UI/RE1P: U1.24 (IO1); also elsewhere on the board
/LCD UI/SW0: U1.26 (IO2); also elsewhere on the board
/LCD UI/SW1: U1.27 (IO3); also elsewhere on the board
/LCD UI/SW2: U1.28 (IO4); also elsewhere on the board
/LCD UI/SW3: U1.1 (IO5); also elsewhere on the board
/MISO: U2.38 (IO19); also elsewhere on the board
/MOSI: U2.36 (IO23); also elsewhere on the board
/Power/~CHRG: R10.1; also elsewhere on the board
/Power/~STDBY: R11.1; also elsewhere on the board
/Q1: U1.4 (OC0); also elsewhere on the board
/Q3: U1.6 (OC2); also elsewhere on the board
/Q4: U1.7 (OC3); also elsewhere on the board
/Q5: U1.8 (OC4); also elsewhere on the board
/Q6: U1.12 (OC5); also elsewhere on the board
/Q7: U1.13 (OC6); also elsewhere on the board
/Q9: U1.15 (OC8); also elsewhere on the board
/Q10: U1.16 (OC9); also elsewhere on the board
/Q11: U1.17 (OC10); also elsewhere on the board
/Q12: U1.18 (OC11); also elsewhere on the board
/RE0A: U2.21 (IO15); also elsewhere on the board
/RE0B: U2.17 (IO14); also elsewhere on the board
/RE1A: U2.20 (IO13); also elsewhere on the board
/RE1B: U2.18 (IO12); also elsewhere on the board
/RXD: R23.2, U2.40 (U0RXD/IO3)
/SCK: U2.35 (IO18); also elsewhere on the board
/SCL: R1.2, U1.9 (SCL), U2.42 (IO21)
/SDA: R2.2, U1.10 (SDA), U2.39 (IO22)
/SS: R7.2, U2.34 (IO5); also elsewhere on the board
/TESTPIN: J1.1, J1.2, U2.15 (IO26)
/TRIG0: R6.2, U2.28 (SD2/IO9); also elsewhere on the board
/TRIG1: R5.2, U2.29 (SD3/IO10); also elsewhere on the board
/TXD: R24.2, U2.41 (U0TXD/IO1)
/USB Serial/RXD: R24.1; also elsewhere on the board
/USB Serial/TXD: R23.1; also elsewhere on the board
/VDD_SDIO: R5.1, R6.1, U2.26 (VDD_SDIO)
/VREF1.5V: R12.2, R22.1, U2.8 (SENSOR_VN)
/VREF3V3: R17.2, R21.1, U2.11 (IO35)
/VREF5V: R15.2, R19.1, U2.6 (SENSOR_CAPP)
/VREF12V: R16.2, R20.1, U2.7 (SENSOR_CAPN)
/VREFBAT: R14.2, R18.1, U2.5 (SENSOR_VP)
/~CHRG: Q1.3 (C), R8.2, U1.3 (IO7)
/~INT: U2.16 (IO27); also elsewhere on the board
/~STDBY: Q2.3 (C), R9.2, U1.2 (IO6)
GND: C1.2, C2.2, D1.2 (A), Q1.2 (E), Q2.2 (E), R4.2, R18.2, R19.2, R20.2, R21.2, R22.2, U1.11 (GND), U2.49 (GND); also elsewhere on the board
unnamed: D1.1 (K), R12.1, R13.2
unnamed: Q1.1 (B), R10.2
unnamed: Q2.1 (B), R11.2
TRIG: U2.14 (IO25); also elsewhere on the board
Vbat: R14.1; also elsewhere on the board

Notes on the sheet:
IO15=1 : U0TXD Printing Control Enable IO12=0 : VDD_SDIO=3.3 else 1.8 IO5 =1 : SDIO Slave rising edge output IO15=1 : SDIO Slave rising edge sampling
V_IO35 = VAT/2
Vbat : 2.7V~4.2V +5V : 5V +12V : 12V +3V3 : 3.3V Vbat : 10:10 : 1/2 : 1.35V~2.10V +5V : 3:10 : 1/4.333 : 1.15V +12V : 0.820:4.7 : 1/6.732 : 1.78V +3V3 : 10:10 : 1/2 : 1.65V

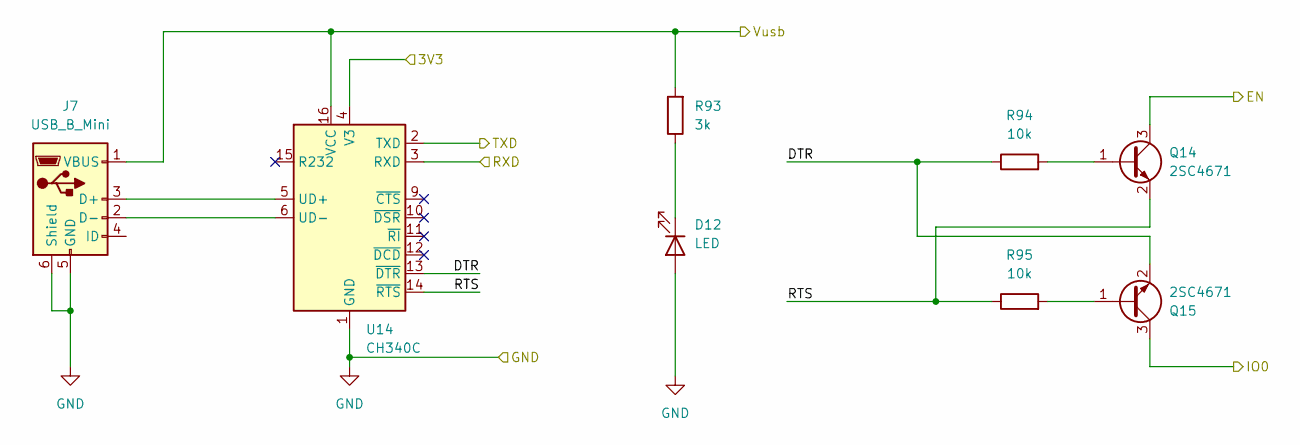
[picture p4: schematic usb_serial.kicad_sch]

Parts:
D12: LED; LED_D3.0mm
J7: USB_B_Mini; USB_Mini-B_Lumberg_2486_01_Horizontal
Q14, Q15: 2SC4671; SOT-523
R93: 3k; R_0402_1005Metric_Pad0.72x0.64mm_HandSolder
R94, R95: 10k; R_0402_1005Metric_Pad0.72x0.64mm_HandSolder
U14: CH340C; SOIC-16_3.9x9.9mm_P1.27mm

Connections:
+3.3V: U14.4 (V3); also elsewhere on the board
/EN: Q14.3 (C); also elsewhere on the board
/IO0: Q15.3 (C); also elsewhere on the board
/USB Serial/DTR: Q15.2 (E), R94.1, U14.13 (~DTR)
/USB Serial/RTS: Q14.2 (E), R95.1, U14.14 (~RTS)
/USB Serial/RXD: U14.3 (RXD); also elsewhere on the board
/USB Serial/TXD: U14.2 (TXD); also elsewhere on the board
GND: D12.2 (A), J7.5 (GND), J7.6 (Shield), U14.1 (GND); also elsewhere on the board
unnamed: D12.1 (K), R93.1
unnamed: J7.3 (D+), U14.5 (UD+)
unnamed: J7.2 (D-), U14.6 (UD-)
unnamed: Q14.1 (B), R94.2
unnamed: Q15.1 (B), R95.2
Vusb: J7.1 (VBUS), R93.2, U14.16 (VCC); also elsewhere on the board

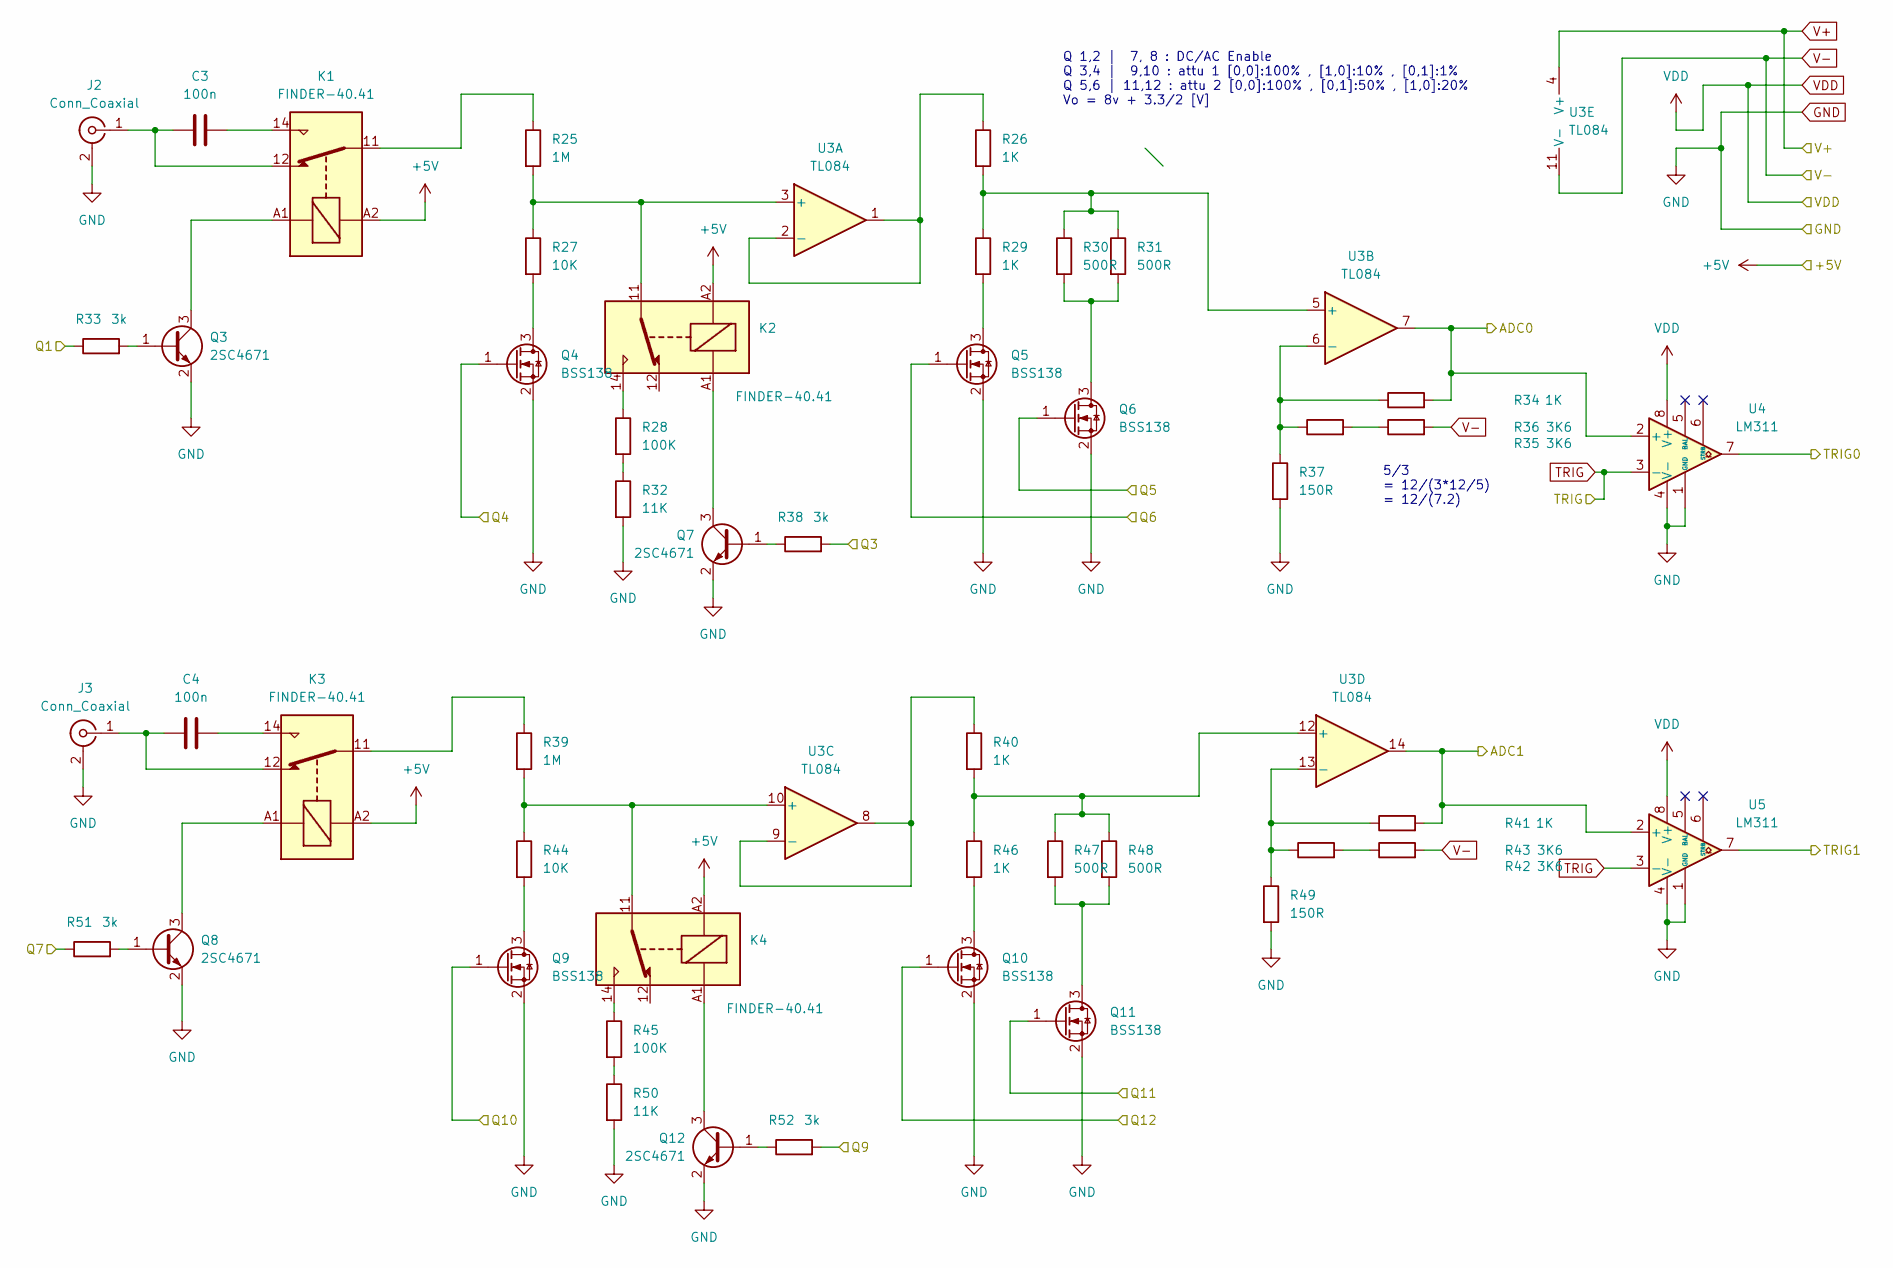
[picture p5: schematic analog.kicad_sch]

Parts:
C3, C4: 100n; C_0402_1005Metric_Pad0.74x0.62mm_HandSolder
J2, J3: Conn_Coaxial; BNC_Amphenol_B6252HB-NPP3G-50_Horizontal
K1, K2, K3, K4: FINDER-40.41; Relay_SPDT_Finder_40.41
Q3, Q7, Q8, Q12: 2SC4671; SOT-523
Q4, Q5, Q6, Q9, Q10, Q11: BSS138; SOT-23_Handsoldering
R25, R39: 1M; R_Axial_DIN0207_L6.3mm_D2.5mm_P10.16mm_Horizontal
R26, R29, R34, R40, R41, R46: 1K; R_Axial_DIN0207_L6.3mm_D2.5mm_P10.16mm_Horizontal
R27, R44: 10K; R_Axial_DIN0207_L6.3mm_D2.5mm_P10.16mm_Horizontal
R28, R45: 100K; R_Axial_DIN0207_L6.3mm_D2.5mm_P10.16mm_Horizontal
R30, R31, R47, R48: 500R; R_Axial_DIN0207_L6.3mm_D2.5mm_P10.16mm_Horizontal
R32, R50: 11K; R_Axial_DIN0207_L6.3mm_D2.5mm_P10.16mm_Horizontal
R33, R38, R51, R52: 3k; R_0402_1005Metric_Pad0.72x0.64mm_HandSolder
R35, R36, R42, R43: 3K6; R_Axial_DIN0207_L6.3mm_D2.5mm_P10.16mm_Horizontal
R37, R49: 150R; R_Axial_DIN0207_L6.3mm_D2.5mm_P10.16mm_Horizontal
U3: TL084; SOIC-14_3.9x8.7mm_P1.27mm
U4, U5: LM311; DIP-8_W7.62mm_LongPads

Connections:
+3.3V: U4.8 (V+), U5.8 (V+); also elsewhere on the board
+5V: K1.A2, K2.A2, K3.A2, K4.A2; also elsewhere on the board
+12V: U3.4 (V+); also elsewhere on the board
-12V: R36.2, R43.2, U3.11 (V-); also elsewhere on the board
/ADC0: R34.2, U3.7, U4.2 (+); also elsewhere on the board
/ADC1: R41.2, U3.14, U5.2 (+); also elsewhere on the board
/Q1: R33.1; also elsewhere on the board
/Q3: R38.2; also elsewhere on the board
/Q4: Q4.1 (G); also elsewhere on the board
/Q5: Q6.1 (G); also elsewhere on the board
/Q6: Q5.1 (G); also elsewhere on the board
/Q7: R51.1; also elsewhere on the board
/Q9: R52.2; also elsewhere on the board
/Q10: Q9.1 (G); also elsewhere on the board
/Q11: Q11.1 (G); also elsewhere on the board
/Q12: Q10.1 (G); also elsewhere on the board
/TRIG0: U4.7; also elsewhere on the board
/TRIG1: U5.7; also elsewhere on the board
GND: J2.2 (Ext), J3.2 (Ext), Q3.2 (E), Q4.2 (S), Q5.2 (S), Q6.2 (S), Q7.2 (E), Q8.2 (E), Q9.2 (S), Q10.2 (S), Q11.2 (S), Q12.2 (E), R32.2, R37.2, R49.2, R50.2, U4.1 (GND), U4.4 (V-), U5.1 (GND), U5.4 (V-); also elsewhere on the board
unnamed: C3.2, K1.14
unnamed: C4.2, K3.14
unnamed: C3.1, J2.1 (In), K1.12
unnamed: C4.1, J3.1 (In), K3.12
unnamed: K1.11, R25.1
unnamed: K2.14, R28.1
unnamed: K3.11, R39.1
unnamed: K4.14, R45.1
unnamed: Q3.1 (B), R33.2
unnamed: K1.A1, Q3.3 (C)
unnamed: Q4.3 (D), R27.2
unnamed: Q5.3 (D), R29.2
unnamed: Q6.3 (D), R30.2, R31.2
unnamed: Q7.1 (B), R38.1
unnamed: K2.A1, Q7.3 (C)
unnamed: Q8.1 (B), R51.2
unnamed: K3.A1, Q8.3 (C)
unnamed: Q9.3 (D), R44.2
unnamed: Q10.3 (D), R46.2
unnamed: Q11.3 (D), R47.2, R48.2
unnamed: Q12.1 (B), R52.1
unnamed: K4.A1, Q12.3 (C)
unnamed: R28.2, R32.1
unnamed: R35.2, R36.1
unnamed: R42.2, R43.1
unnamed: R45.2, R50.1
unnamed: K2.11, R25.2, R27.1, U3.3 (+)
unnamed: R26.1, U3.1, U3.2 (-)
unnamed: R26.2, R29.1, R30.1, R31.1, U3.5 (+)
unnamed: R34.1, R35.1, R37.1, U3.6 (-)
unnamed: K4.11, R39.2, R44.1, U3.10 (+)
unnamed: R40.1, U3.8, U3.9 (-)
unnamed: R40.2, R46.1, R47.1, R48.1, U3.12 (+)
unnamed: R41.1, R42.1, R49.1, U3.13 (-)
TRIG: U4.3 (-), U5.3 (-); also elsewhere on the board

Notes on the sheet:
Q 1,2 | 7, 8 : DC/AC Enable Q 3,4 | 9,10 : attu 1 [0,0]:100% , [1,0]:10% , [0,1]:1% Q 5,6 | 11,12 : attu 2 [0,0]:100% , [0,1]:50% , [1,0]:20% Vo = 8v + 3.3/2 [V]
5/3 = 12/(3*12/5) = 12/(7.2)

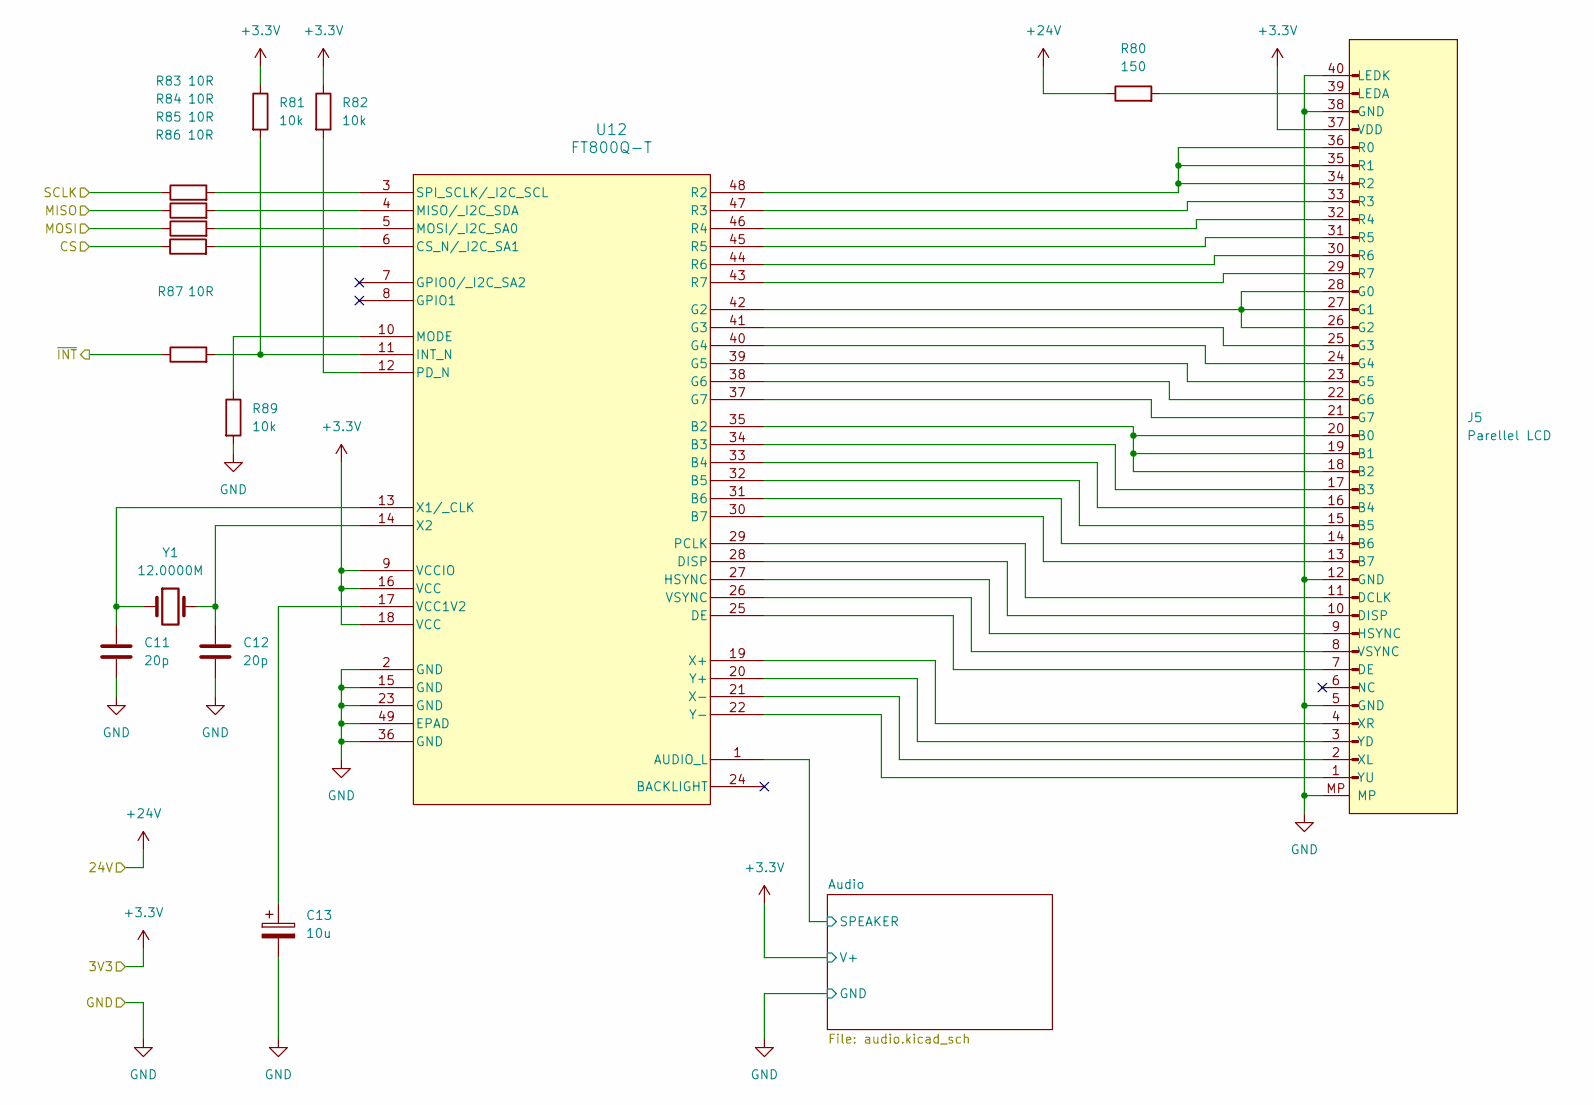
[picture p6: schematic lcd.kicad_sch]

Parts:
C11, C12: 20p; C_0402_1005Metric_Pad0.74x0.62mm_HandSolder
C13: 10u; CP_Elec_5x5.3
J5: Parellel LCD; TE_4-1734839-0_1x40-1MP_P0.5mm_Horizontal
R80: 150; R_0402_1005Metric_Pad0.72x0.64mm_HandSolder
R81, R82, R89: 10k; R_0402_1005Metric_Pad0.72x0.64mm_HandSolder
R83, R84, R85, R86, R87: 10R; R_1206_3216Metric_Pad1.30x1.75mm_HandSolder
U12: FT800Q-T; VQFN-48-1EP_7x7mm_P0.5mm_EP4.1x4.1mm
Y1: 12.0000M; Crystal_HC49-4H_Vertical

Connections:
+3.3V: J5.37 (VDD), R81.1, R82.1, U12.9 (VCCIO), U12.16 (VCC), U12.18 (VCC); also elsewhere on the board
+24V: R80.1; also elsewhere on the board
/LCD/Audio/SPEAKER: U12.1 (AUDIO_L); also elsewhere on the board
/MISO: R84.1; also elsewhere on the board
/MOSI: R85.1; also elsewhere on the board
/SCK: R83.1; also elsewhere on the board
/SS: R86.1; also elsewhere on the board
/~INT: R87.1; also elsewhere on the board
GND: C11.2, C12.2, C13.2, J5.5 (GND), J5.12 (GND), J5.38 (GND), J5.40 (LEDK), J5.MP, R89.2, U12.2 (GND), U12.15 (GND), U12.23 (GND), U12.36 (GND), U12.49 (EPAD); also elsewhere on the board
unnamed: J5.18 (B2), J5.19 (B1), J5.20 (B0), U12.35 (B2)
unnamed: J5.17 (B3), U12.34 (B3)
unnamed: J5.16 (B4), U12.33 (B4)
unnamed: J5.15 (B5), U12.32 (B5)
unnamed: J5.14 (B6), U12.31 (B6)
unnamed: J5.13 (B7), U12.30 (B7)
unnamed: J5.11 (DCLK), U12.29 (PCLK)
unnamed: J5.7 (DE), U12.25 (DE)
unnamed: J5.10 (DISP), U12.28 (DISP)
unnamed: J5.26 (G2), J5.27 (G1), J5.28 (G0), U12.42 (G2)
unnamed: J5.25 (G3), U12.41 (G3)
unnamed: J5.24 (G4), U12.40 (G4)
unnamed: J5.23 (G5), U12.39 (G5)
unnamed: J5.22 (G6), U12.38 (G6)
unnamed: J5.21 (G7), U12.37 (G7)
unnamed: J5.9 (HSYNC), U12.27 (HSYNC)
unnamed: J5.39 (LEDA), R80.2
unnamed: J5.34 (R2), J5.35 (R1), J5.36 (R0), U12.48 (R2)
unnamed: J5.33 (R3), U12.47 (R3)
unnamed: J5.32 (R4), U12.46 (R4)
unnamed: J5.31 (R5), U12.45 (R5)
unnamed: J5.30 (R6), U12.44 (R6)
unnamed: J5.29 (R7), U12.43 (R7)
unnamed: J5.8 (VSYNC), U12.26 (VSYNC)
unnamed: J5.2 (XL), U12.21 (X-)
unnamed: J5.4 (XR), U12.19 (X+)
unnamed: J5.3 (YD), U12.20 (Y+)
unnamed: J5.1 (YU), U12.22 (Y-)
unnamed: R86.2, U12.6 (CS_N/_I2C_SA1)
unnamed: R81.2, R87.2, U12.11 (INT_N)
unnamed: R84.2, U12.4 (MISO/_I2C_SDA)
unnamed: R89.1, U12.10 (MODE)
unnamed: R85.2, U12.5 (MOSI/_I2C_SA0)
unnamed: R82.2, U12.12 (PD_N)
unnamed: R83.2, U12.3 (SPI_SCLK/_I2C_SCL)
unnamed: C13.1, U12.17 (VCC1V2)
unnamed: C11.1, U12.13 (X1/_CLK), Y1.1
unnamed: C12.1, U12.14 (X2), Y1.2

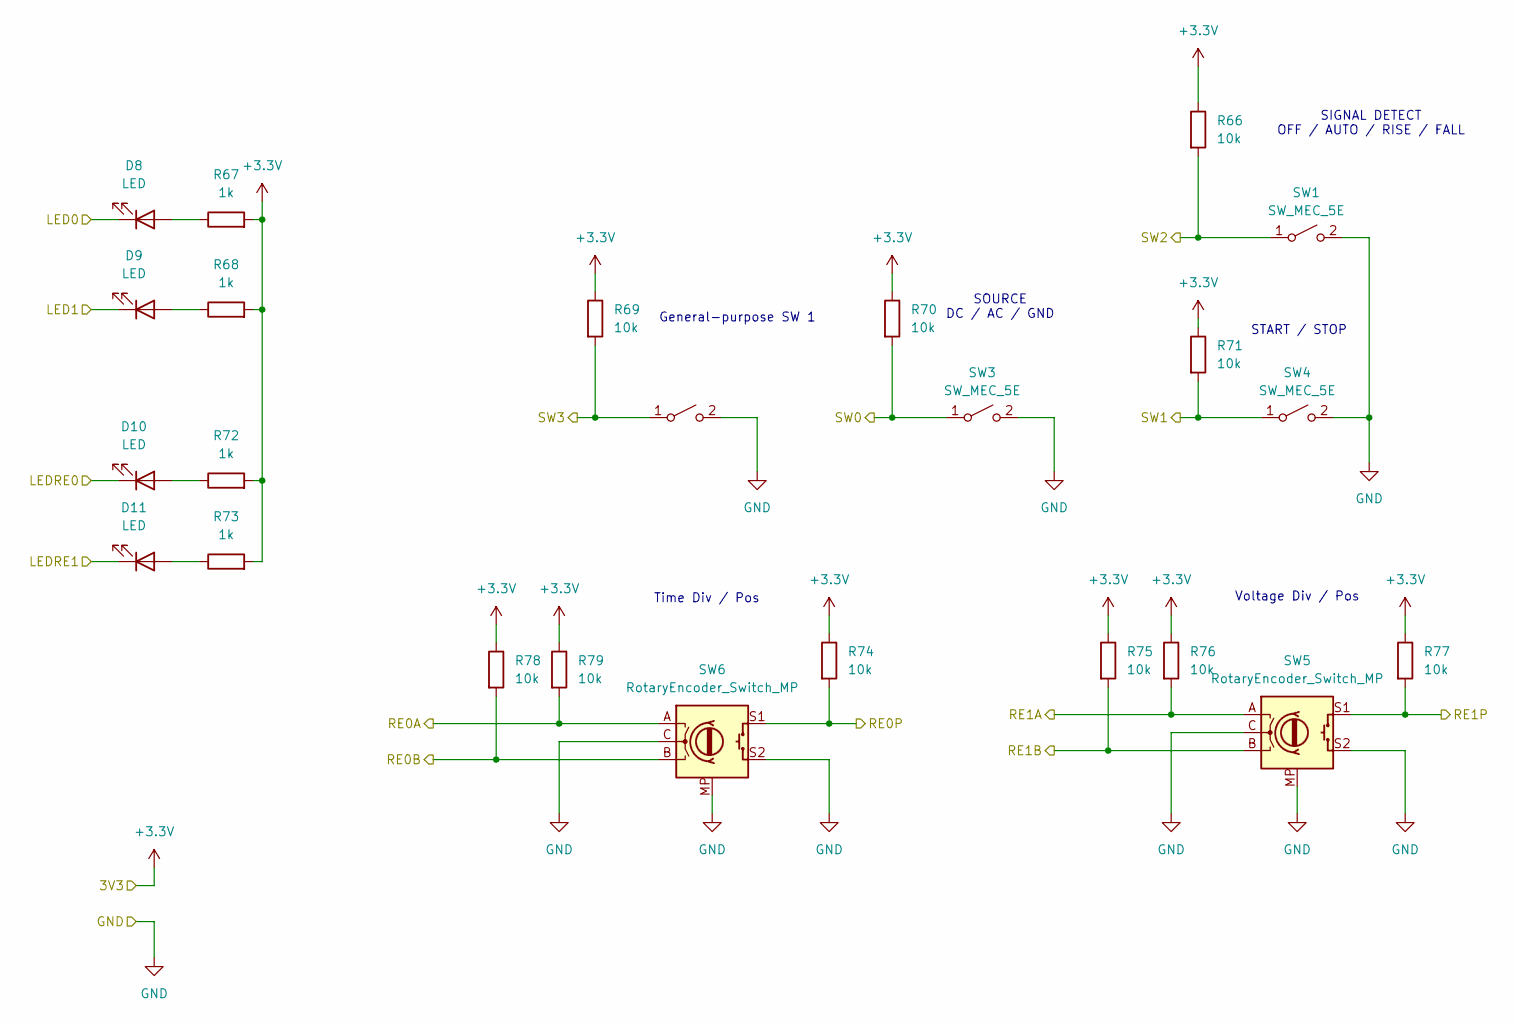
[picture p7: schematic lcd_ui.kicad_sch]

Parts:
D8, D9, D10, D11: LED; LED_D3.0mm
R66, R69, R70, R71, R74, R75, R76, R77, R78, R79: 10k; R_0402_1005Metric_Pad0.72x0.64mm_HandSolder
R67, R68, R72, R73: 1k; R_0603_1608Metric_Pad0.98x0.95mm_HandSolder
SW1, SW2, SW3, SW4: SW_MEC_5E; SW_PUSH_6mm_H4.3mm
SW5, SW6: RotaryEncoder_Switch_MP; RotaryEncoder_Alps_EC11E-Switch_Vertical_H20mm_MountingHoles

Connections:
+3.3V: R66.1, R67.2, R68.2, R69.1, R70.1, R71.1, R72.2, R73.2, R74.1, R75.1, R76.1, R77.1, R78.1, R79.1; also elsewhere on the board
/LCD UI/LED0: D8.1 (K); also elsewhere on the board
/LCD UI/LED1: D9.1 (K); also elsewhere on the board
/LCD UI/LEDRE0: D10.1 (K); also elsewhere on the board
/LCD UI/LEDRE1: D11.1 (K); also elsewhere on the board
/LCD UI/RE0P: R74.2, SW6.S1; also elsewhere on the board
/LCD UI/RE1P: R77.2, SW5.S1; also elsewhere on the board
/LCD UI/SW0: R70.2, SW3.1 (A); also elsewhere on the board
/LCD UI/SW1: R71.2, SW4.1 (A); also elsewhere on the board
/LCD UI/SW2: R66.2, SW1.1 (A); also elsewhere on the board
/LCD UI/SW3: R69.2, SW2.1 (A); also elsewhere on the board
/RE0A: R79.2, SW6.A; also elsewhere on the board
/RE0B: R78.2, SW6.B; also elsewhere on the board
/RE1A: R76.2, SW5.A; also elsewhere on the board
/RE1B: R75.2, SW5.B; also elsewhere on the board
GND: SW1.2 (B), SW2.2 (B), SW3.2 (B), SW4.2 (B), SW5.C, SW5.MP, SW5.S2, SW6.C, SW6.MP, SW6.S2; also elsewhere on the board
unnamed: D8.2 (A), R67.1
unnamed: D9.2 (A), R68.1
unnamed: D10.2 (A), R72.1
unnamed: D11.2 (A), R73.1

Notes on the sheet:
SIGNAL DETECT OFF / AUTO / RISE / FALL
General-purpose SW 1
START / STOP
SOURCE DC / AC / GND
Voltage Div / Pos
Time Div / Pos

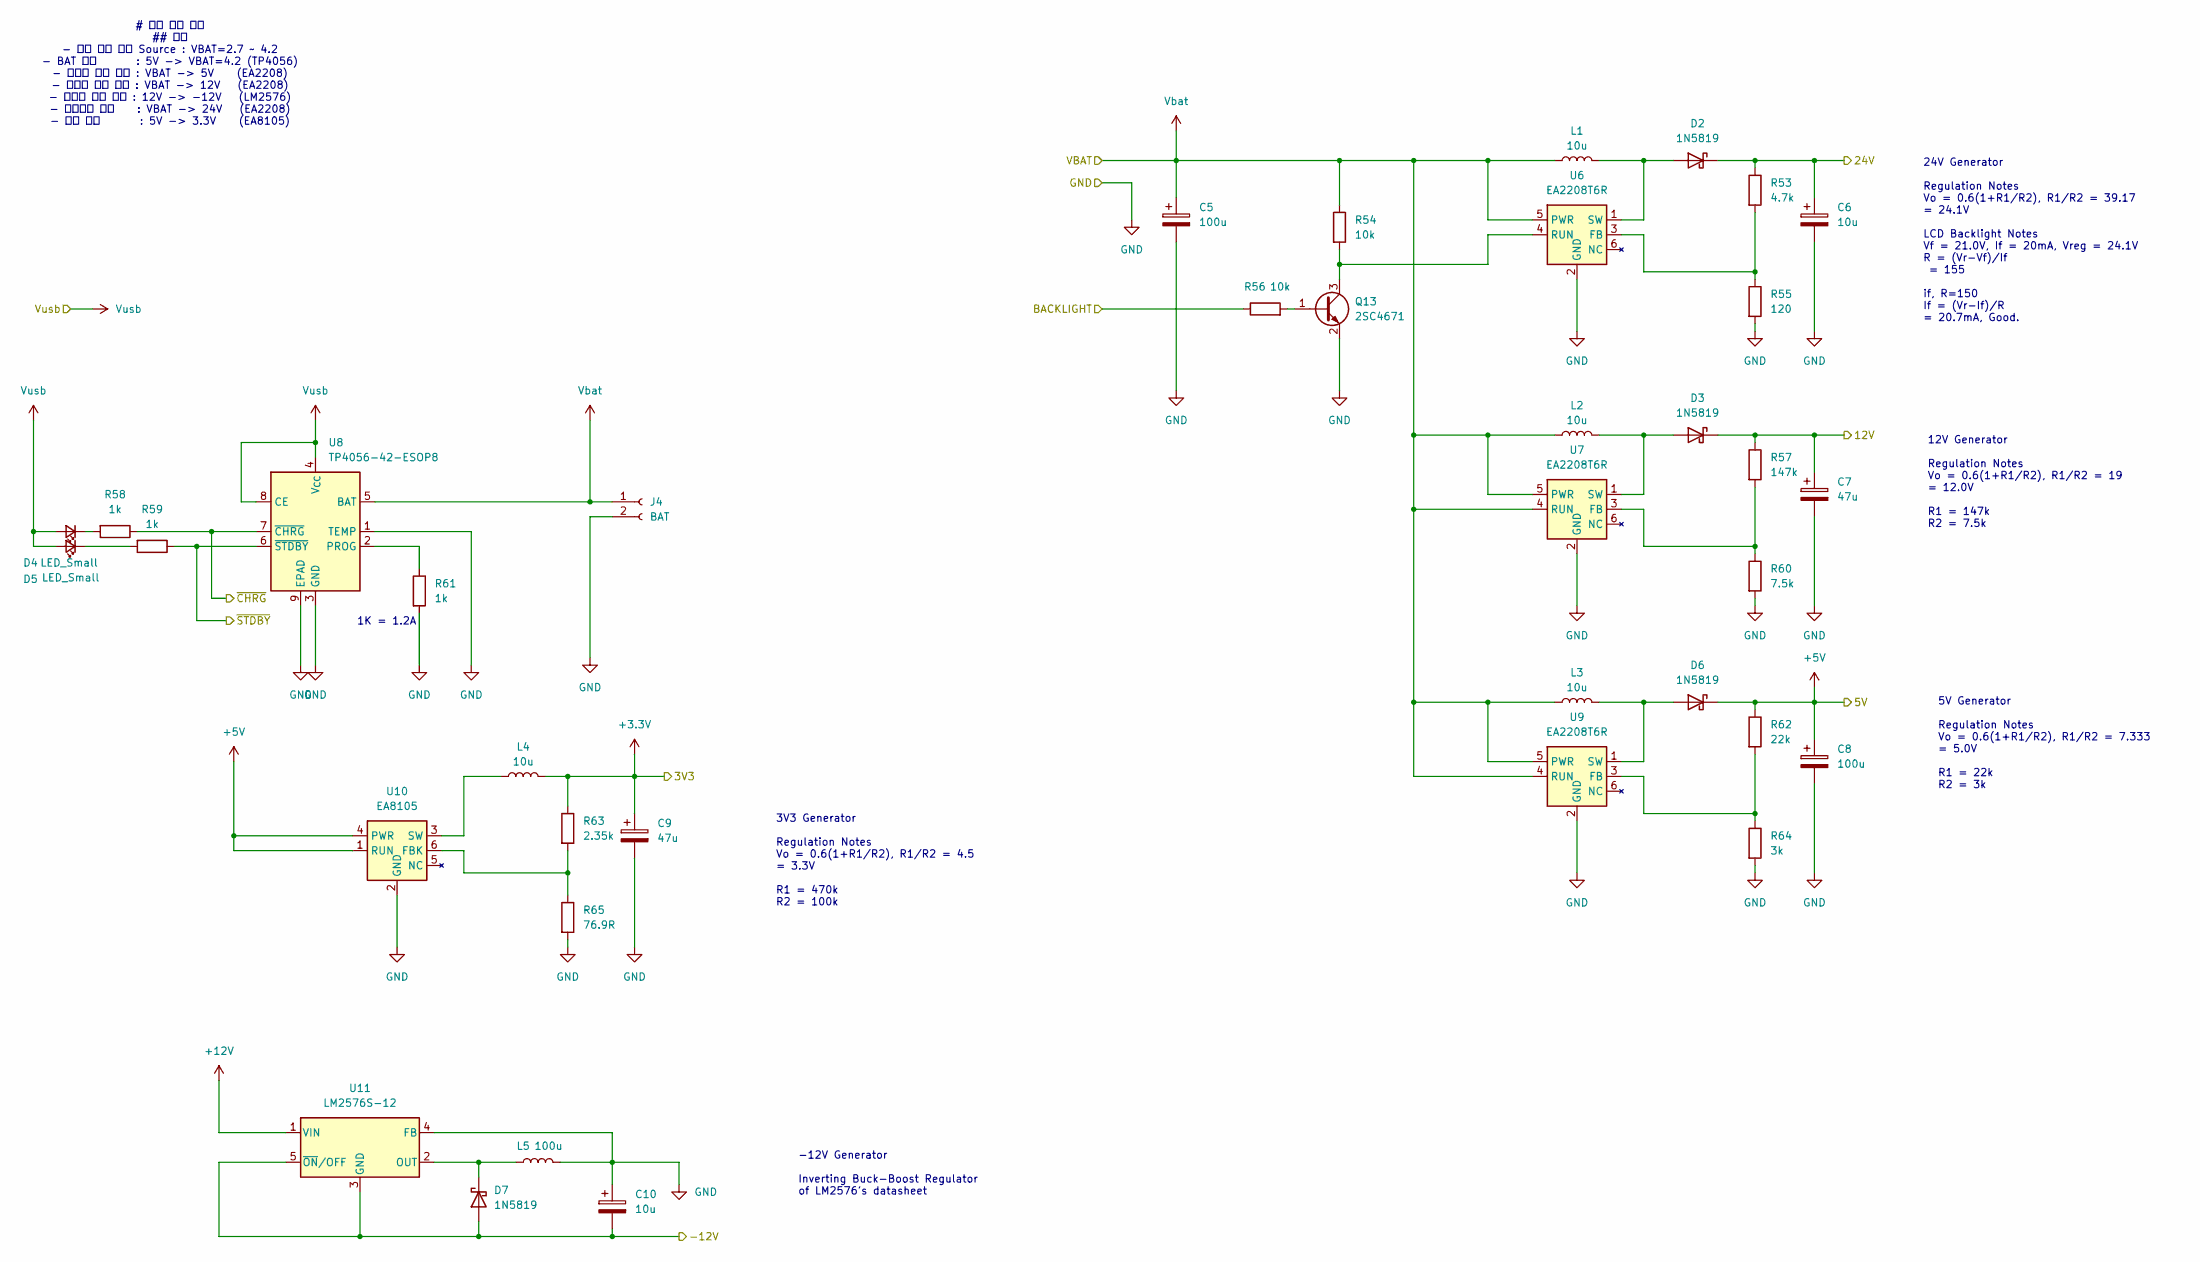
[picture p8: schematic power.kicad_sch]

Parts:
C5, C8: 100u; CP_Elec_5x5.3
C6: 10u; CP_Elec_5x5.3
C7: 47u; CP_Elec_5x5.3
C9: 47u; CP_Elec_6.3x5.7
C10: 10u; CP_Elec_6.3x5.7
D2, D3, D6, D7: 1N5819; D_SOD-123
D4, D5: LED_Small; LED_D3.0mm
J4: BAT; PinSocket_1x02_P2.54mm_Vertical
L1, L2, L3, L4: 10u; L_7.3x7.3_H3.5
L5: 100u; L_7.3x7.3_H3.5
Q13: 2SC4671; SOT-523
R53: 4.7k; R_0402_1005Metric_Pad0.72x0.64mm_HandSolder
R54, R56: 10k; R_0402_1005Metric_Pad0.72x0.64mm_HandSolder
R55: 120; R_0402_1005Metric_Pad0.72x0.64mm_HandSolder
R57: 147k; R_0402_1005Metric_Pad0.72x0.64mm_HandSolder
R58, R59, R61: 1k; R_0603_1608Metric_Pad0.98x0.95mm_HandSolder
R60: 7.5k; R_1206_3216Metric_Pad1.30x1.75mm_HandSolder
R62: 22k; R_1206_3216Metric_Pad1.30x1.75mm_HandSolder
R63: 2.35k; R_0402_1005Metric_Pad0.72x0.64mm_HandSolder
R64: 3k; R_0402_1005Metric_Pad0.72x0.64mm_HandSolder
R65: 76.9R; R_0402_1005Metric_Pad0.72x0.64mm_HandSolder
U6, U7, U9: EA2208T6R; SOT-23-6
U8: TP4056-42-ESOP8; SOIC-8-1EP_3.9x4.9mm_P1.27mm_EP2.41x3.3mm_ThermalVias
U10: EA8105; SOT-23-6
U11: LM2576S-12; TO-263-5_TabPin3

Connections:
+3.3V: C9.1, L4.2, R63.1; also elsewhere on the board
+5V: C8.1, D6.1 (K), R62.1, U10.1 (RUN), U10.4 (PWR); also elsewhere on the board
+12V: C7.1, D3.1 (K), R57.1, U11.1 (VIN); also elsewhere on the board
+24V: C6.1, D2.1 (K), R53.1; also elsewhere on the board
-12V: C10.2, D7.2 (A), U11.3 (GND), U11.5 (~ON/OFF); also elsewhere on the board
/BACKLIGHT: R56.1; also elsewhere on the board
/Power/~CHRG: R58.1, U8.7 (~CHRG); also elsewhere on the board
/Power/~STDBY: R59.1, U8.6 (~STDBY); also elsewhere on the board
GND: C5.2, C6.2, C7.2, C8.2, C9.2, C10.1, J4.2, L5.2, Q13.2 (E), R55.2, R60.2, R61.2, R64.2, R65.2, U6.2 (GND), U7.2 (GND), U8.1 (TEMP), U8.3 (GND), U8.9 (EPAD), U9.2 (GND), U10.2 (GND), U11.4 (FB); also elsewhere on the board
unnamed: D2.2 (A), L1.2, U6.1 (SW)
unnamed: D3.2 (A), L2.2, U7.1 (SW)
unnamed: D4.1 (K), R58.2
unnamed: D5.1 (K), R59.2
unnamed: D6.2 (A), L3.2, U9.1 (SW)
unnamed: D7.1 (K), L5.1, U11.2 (OUT)
unnamed: Q13.1 (B), R56.2
unnamed: Q13.3 (C), R54.2, U6.4 (RUN)
unnamed: R53.2, R55.1, U6.3 (FB)
unnamed: R57.2, R60.1, U7.3 (FB)
unnamed: R61.1, U8.2 (PROG)
unnamed: R62.2, R64.1, U9.3 (FB)
unnamed: R63.2, R65.1, U10.6 (FBK)
unnamed: L4.1, U10.3 (SW)
Vbat: C5.1, J4.1, L1.1, L2.1, L3.1, R54.1, U6.5 (PWR), U7.4 (RUN), U7.5 (PWR), U8.5 (BAT), U9.4 (RUN), U9.5 (PWR); also elsewhere on the board
Vusb: D4.2 (A), D5.2 (A), U8.4 (V_{CC}), U8.8 (CE); also elsewhere on the board

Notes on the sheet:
24V Generator Regulation Notes Vo = 0.6(1+R1/R2), R1/R2 = 39.17 = 24.1V LCD Backlight Notes Vf = 21.0V, If = 20mA, Vreg = 24.1V R = (Vr-Vf)/If = 155 if, R=150 If = (Vr-If)/R = 20.7mA, Good.
1K = 1.2A
-12V Generator Inverting Buck-Boost Regulator of LM2576's datasheet
12V Generator Regulation Notes Vo = 0.6(1+R1/R2), R1/R2 = 19 = 12.0V R1 = 147k R2 = 7.5k
# 최종 확정 사항 ## 전원 - 상시 전원 공급 Source : VBAT=2.7 ~ 4.2 - BAT 충전 : 5V -> VBAT=4.2 (TP4056) - 배터리 승압 회로 : VBAT -> 5V (EA2208) - 양전압 생성 회로 : VBAT -> 12V (EA2208) - 음전압 생성 회로 : 12V -> -12V (LM2576) - 백라이트 회로 : VBAT -> 24V (EA2208) - 강하 회로 : 5V -> 3.3V (EA8105)
5V Generator Regulation Notes Vo = 0.6(1+R1/R2), R1/R2 = 7.333 = 5.0V R1 = 22k R2 = 3k
3V3 Generator Regulation Notes Vo = 0.6(1+R1/R2), R1/R2 = 4.5 = 3.3V R1 = 470k R2 = 100k

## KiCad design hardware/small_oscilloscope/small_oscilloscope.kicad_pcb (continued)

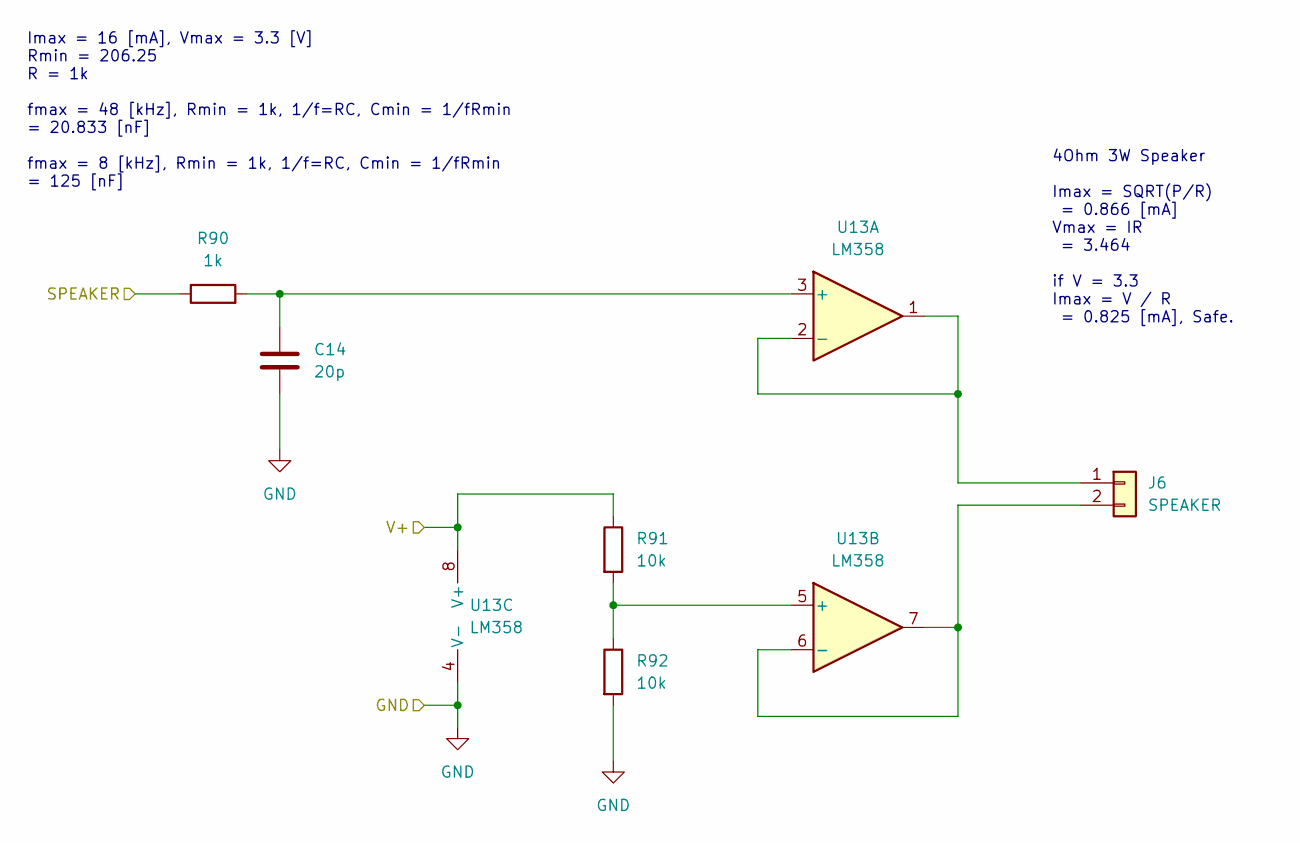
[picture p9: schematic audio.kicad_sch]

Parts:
C14: 20p; C_0402_1005Metric_Pad0.74x0.62mm_HandSolder
J6: SPEAKER; PinSocket_1x02_P2.54mm_Vertical
R90: 1k; R_0603_1608Metric_Pad0.98x0.95mm_HandSolder
R91, R92: 10k; R_0402_1005Metric_Pad0.72x0.64mm_HandSolder
U13: LM358; SOIC-8_3.9x4.9mm_P1.27mm

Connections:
+3.3V: R91.1, U13.8 (V+); also elsewhere on the board
/LCD/Audio/SPEAKER: R90.1; also elsewhere on the board
GND: C14.2, R92.2, U13.4 (V-); also elsewhere on the board
unnamed: J6.1, U13.1, U13.2 (-)
unnamed: J6.2, U13.6 (-), U13.7
unnamed: C14.1, R90.2, U13.3 (+)
unnamed: R91.2, R92.1, U13.5 (+)

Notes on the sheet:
Imax = 16 [mA], Vmax = 3.3 [V] Rmin = 206.25 R = 1k fmax = 48 [kHz], Rmin = 1k, 1/f=RC, Cmin = 1/fRmin = 20.833 [nF] fmax = 8 [kHz], Rmin = 1k, 1/f=RC, Cmin = 1/fRmin = 125 [nF]
4Ohm 3W Speaker Imax = SQRT(P/R) = 0.866 [mA] Vmax = IR = 3.464 if V = 3.3 Imax = V / R = 0.825 [mA], Safe.

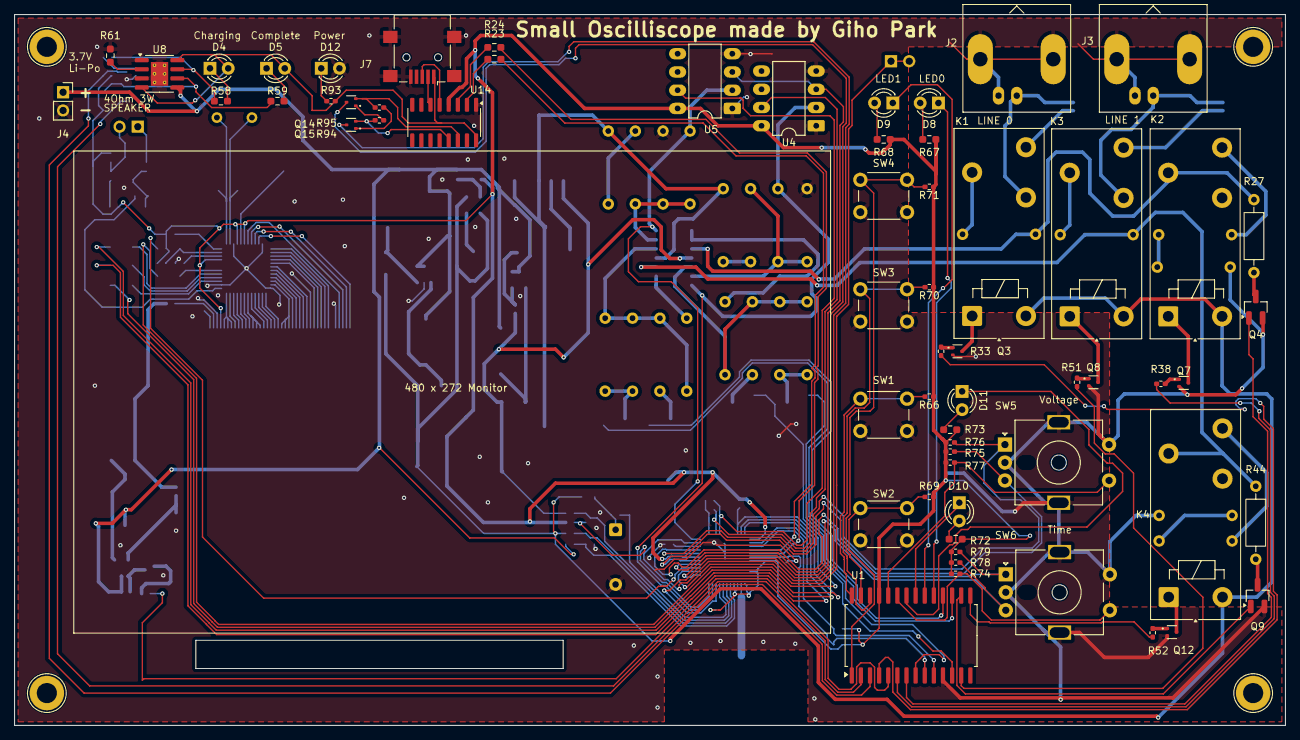
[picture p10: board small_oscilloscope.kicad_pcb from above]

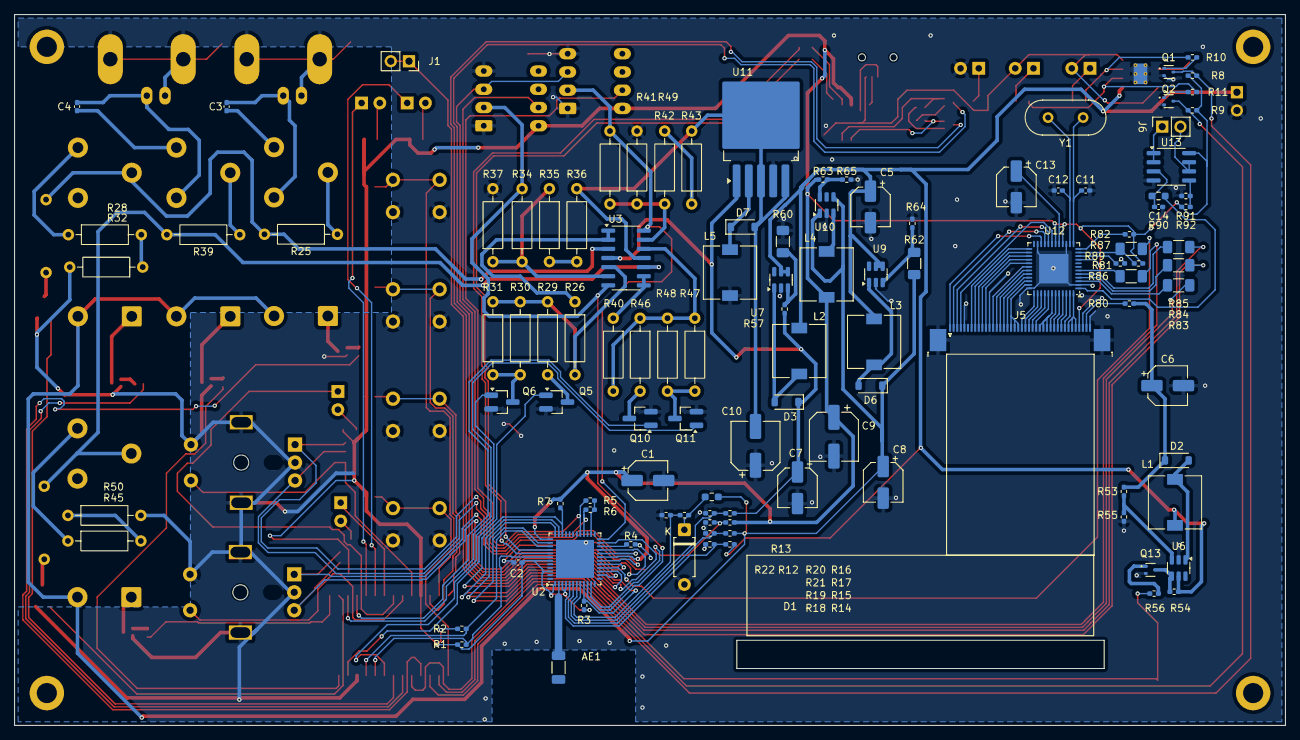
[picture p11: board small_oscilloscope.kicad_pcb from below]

Board: 2 copper layers, 177.0 x 99.0 mm, 173 parts (111 on the bottom side), 169 nets.

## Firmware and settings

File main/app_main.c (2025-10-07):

#include <stdio.h>
#include <string.h>
#include "freertos/FreeRTOS.h"
#include "freertos/task.h"
#include "freertos/queue.h"
#include "esp_log.h"
#include "driver/i2c.h"
#include "driver/spi_master.h"
#include "esp_timer.h"
#include "ft800.h"
#include "hardware_test.h"
#include "interactive_test.h"
//#include "esp_adc/adc_oneshot.h"
//#include "esp_adc/adc_cali.h"
//#include "esp_adc/adc_cali_scheme.h"
#include <inttypes.h>

static const char *TAG = "SMALL_OSCILLOSCOPE";

// FT800 핸들
static ft800_handle_t lcd;

// FT800 인터럽트 핸들러
static void IRAM_ATTR ft800_isr_handler(void* arg) {
    // 인터럽트 처리 로직
    // 여기서는 간단히 플래그만 설정
    (void)arg;  // 사용하지 않는 변수 경고 제거
}

// FT800 화면 테스트 태스크
static void ft800_test_task(void *pvParameters) {
    ESP_LOGI(TAG, "Starting FT800 display test task");
    

    // FT800 초기화
    if (!initFT800()) {
        ESP_LOGI(TAG, "FT800 test passed");
    } else {
        ESP_LOGE(TAG, "FT800 test failed");
    }
    vTaskDelay(pdMS_TO_TICKS(1000));

    spi_speedup();
    
	clrscr();
    

	lcd_start_screen(0);
	cmd(DISPLAY());
	cmd(CMD_SWAP);	
    
    ESP_LOGI(TAG, "FT800 display test completed successfully");
    
    // 메인 루프 - 주기적으로 색상 변경
    int test_phase = 0;
    while (1) {
		static uint32_t frames = 0;
        uint32_t frames_old = frames;
        frames = HOST_MEM_RD32(REG_FRAMES);
        if(frames_old != frames)
        {
            lcd_start_screen(frames);
            //ESP_LOGI(TAG, "FRAMES: %ld", frames);

            char str[100];
            sprintf(str, "FRAMES: %ld", frames);
            cmd(COLOR_RGB(0xDE,0xDE,0xDE));
            cmd_text(10,230, 27,0, str);
            
            memset(str, 0, sizeof(str));
            sprintf(str, "GPIO12 = %d", gpio_get_level(12));
            cmd(COLOR_RGB(0xDE,0xDE,0xDE));
            cmd_text(470,230, 26,OPT_RIGHTX, str);

            cmd(DISPLAY());
            cmd(CMD_SWAP);	

            if((frames%60) == 10){
                //ESP_LOGI(TAG, "FRAMES: %ld", frames);
                HOST_MEM_WR8(REG_VOL_SOUND, 0xFF);      	
                switch((frames%180)/60){
                    case 0:
                        HOST_MEM_WR16(REG_SOUND, 0x50);      	//C8 MIDI xylophone
                        break;
                    case 1:
                        HOST_MEM_WR16(REG_SOUND, 0x51);      	//C8 MIDI xylophone
                        break;
                    case 2:
                        HOST_MEM_WR16(REG_SOUND, 0x56);      	//C8 MIDI xylophone
                        break;
                }
                HOST_MEM_WR8(REG_PLAY, 1); 
            }
            
        }
        vTaskDelay(pdMS_TO_TICKS(1));
    }
}

// 하드웨어 테스트 태스크
static void hardware_test_task(void *pvParameters) {
    ESP_LOGI(TAG, "Starting complete hardware test...");
    
    // 하드웨어 테스트 실행
    hardware_test_results_t test_results;
    esp_err_t ret = run_hardware_test(&test_results);
    
    if (ret == ESP_OK) {
        print_hardware_test_results(&test_results);
        ESP_LOGI(TAG, "Hardware test completed successfully");
    } else {
        ESP_LOGE(TAG, "Hardware test failed: %s", esp_err_to_name(ret));
    }
    // 상호작용 테스트 시작
    start_interactive_test();
    
    // 테스트 완료 후 태스크 종료
    vTaskDelete(NULL);
}

void app_main(void) {
    ESP_LOGI(TAG, "Small Oscilloscope Starting (Simple Version)...");
    
    // 하드웨어 테스트 태스크 시작
    xTaskCreate(hardware_test_task, "hardware_test_task", 8192, NULL, 5, NULL);
    
    // 메인 루프
    while (1) {
        vTaskDelay(pdMS_TO_TICKS(5000));
        ESP_LOGI(TAG, "Small Oscilloscope running - check serial output for real-time data");
    }
} 

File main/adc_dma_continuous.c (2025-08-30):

#include <stdio.h>
#include <stdlib.h>
#include <string.h>
#include <inttypes.h>
#include "freertos/FreeRTOS.h"
#include "freertos/task.h"
#include "freertos/queue.h"
#include "freertos/semphr.h"
#include "adc_dma_continuous.h"

#include "esp_log.h"
#include "esp_err.h"
#include "esp_adc/adc_continuous.h"
#include "esp_adc/adc_oneshot.h"
#include "esp_adc/adc_cali.h"
#include "esp_adc/adc_cali_scheme.h"
#include "driver/gpio.h"

static const char *TAG = "ADC_CONTINUOUS";

// ADC 설정
#define ADC_UNIT                    ADC_UNIT_1
#define ADC_CONV_MODE               ADC_CONV_SINGLE_UNIT_1
#define ADC_OUTPUT_TYPE             ADC_DIGI_OUTPUT_FORMAT_TYPE1
#define ADC_ATTEN                   ADC_ATTEN_DB_12  // 0~3.9V 범위
#define ADC_BITWIDTH                ADC_BITWIDTH_12   // 12비트

// ADC 채널 설정 (ADC1만 사용 - WiFi 충돌 방지)
#define ADC_CONTINUOUS_CHANNEL_NUM  2
#define ADC_CONTINUOUS_CHANNEL_0    ADC_CHANNEL_6  // GPIO34
#define ADC_CONTINUOUS_CHANNEL_1    ADC_CHANNEL_7  // GPIO35

// ADC Polling 채널 설정 (ADC1 사용)
#define ADC_POLLING_CHANNEL_0       ADC_CHANNEL_0  // GPIO36 (ADC1_CH0)
#define ADC_POLLING_CHANNEL_1       ADC_CHANNEL_1  // GPIO37 (ADC1_CH1)
#define ADC_POLLING_CHANNEL_2       ADC_CHANNEL_2  // GPIO38 (ADC1_CH2)
#define ADC_POLLING_CHANNEL_3       ADC_CHANNEL_3  // GPIO39 (ADC1_CH3)


// ADC 결과 구조체
typedef struct {
    uint32_t continuous_ch0_data[ADC_BUFFER_SIZE];  // GPIO34 (Continuous)
    uint32_t continuous_ch1_data[ADC_BUFFER_SIZE];  // GPIO35 (Continuous)
    uint32_t polling_ch0_data[ADC_POLLING_BUFFER_SIZE];     // GPIO32 (Polling)
    uint32_t polling_ch1_data[ADC_POLLING_BUFFER_SIZE];     // GPIO33 (Polling)
    uint32_t polling_ch2_data[ADC_POLLING_BUFFER_SIZE];     // GPIO33 (Polling)
    uint32_t polling_ch3_data[ADC_POLLING_BUFFER_SIZE];     // GPIO33 (Polling)
    uint32_t buffer_index;
    bool buffer_full;
    int cnt;
    uint32_t polling_index;
} adc_data_t;

// EventGroup 비트 정의
#define ADC_CONTINUOUS_RUNNING_BIT    BIT0
#define ADC_POLLING_REQUEST_BIT       BIT1

// 전역 변수
adc_continuous_handle_t adc_continuous_handle = NULL;
adc_oneshot_unit_handle_t adc_oneshot_handle = NULL;
adc_cali_handle_t adc1_cali_handle = NULL;
adc_data_t adc_data = {0};
SemaphoreHandle_t adc_data_mutex = NULL;
QueueHandle_t adc_queue = NULL;
bool adc_continuous_running = false;
TaskHandle_t polling_task_handle = NULL;
EventGroupHandle_t adc_event_group = NULL;

// ADC Continuous Mode 콜백 함수
static bool IRAM_ATTR s_conv_done_cb(adc_continuous_handle_t handle, const adc_continuous_evt_data_t *edata, void *user_data)
{
    BaseType_t must_yield = pdFALSE;
    
    // 큐가 NULL이 아닌지 확인
    if (adc_queue != NULL) {
        // ADC 데이터를 큐에 전송
        xQueueSendFromISR(adc_queue, edata, &must_yield);
    }
    
    return (must_yield == pdTRUE);
}

// ADC 캘리브레이션 초기화
static esp_err_t adc_calibration_init(adc_unit_t unit, adc_channel_t channel, adc_atten_t atten, adc_cali_handle_t *out_handle)
{
    adc_cali_handle_t handle = NULL;
    esp_err_t ret = ESP_FAIL;
    bool calibrated = false;

    if (!calibrated) {
        ESP_LOGI(TAG, "calibration scheme version is %s", "Line Fitting");
        adc_cali_line_fitting_config_t cali_config = {
            .unit_id = unit,
            .atten = atten,
            .bitwidth = ADC_BITWIDTH_DEFAULT,
        };
        ret = adc_cali_create_scheme_line_fitting(&cali_config, &handle);
        if (ret == ESP_OK) {
            calibrated = true;
        }
    }

    *out_handle = handle;
    if (ret == ESP_OK) {
        ESP_LOGI(TAG, "ADC Calibration Success");
    } else if (ret == ESP_ERR_NOT_SUPPORTED || !calibrated) {
        ESP_LOGW(TAG, "eFuse not burnt, skip software calibration");
    } else {
        ESP_LOGE(TAG, "Invalid arg or no memory");
    }

    return ret;
}
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

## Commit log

2025-06-25 infra: ESP-IDF 프로젝트 기본 구조 생성
    [analog.kicad_sch, audio.kicad_sch, lcd_ui.kicad_sch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]
2025-06-26 250627 circuit
    [analog.kicad_sch, audio.kicad_sch, lcd.kicad_sch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]
2025-06-27 feat: 오실로스코프 회로 설계 업데이트
    [analog.kicad_sch, audio.kicad_sch, lcd.kicad_sch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]
2025-06-27 chore: KiCad 프로젝트 백업 파일 정리 및 PCB 파일 업데이트
    [small_oscilloscope.kicad_pcb]
2025-06-27 feat: 소형 오실로스코프 하드웨어 개발 완료
    [small_oscilloscope.kicad_pcb]
2025-07-07 board edit
    [lcd.kicad_sch, lcd_ui.kicad_sch, small_oscilloscope.kicad_pcb]
2025-08-20 oscilliscope first success
    [analog.kicad_sch, audio.kicad_sch, lcd.kicad_sch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]
2025-09-06 feat: ft800 problem debug add
    [ft800.c]
2025-10-07 fix: program tidy
    [analog.kicad_sch, power.kicad_sch]
